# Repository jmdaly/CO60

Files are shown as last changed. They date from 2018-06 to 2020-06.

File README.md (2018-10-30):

# CO60 PCB

The CO60 was developed out of the desire to produce a 60% PCB that
appeals to many people and is readily available. CO60 is a portmanteau
of Community and 60% keyboard.

## Overview

The CO60 aims to meet the following design goals:

* Switches oriented such that the LEDs are South-facing, for
  compatibility with Cherry profile keycaps.

* USB Type-C support in both A to C and C to C configurations.

* QMK support.

* A variety of split spacebar configurations, including split 6.25U
  space and split 7U space.

* ESD protection circuitry, including data line protection and a
  polyfuse on the VCC line.

* Support for per-switch LED backlighting.

* Fits in standard 60% keyboard cases.

## Supported Layouts

The CO60 supports the [the following layouts](http://www.keyboard-layout-editor.com/#/gists/b488496b3a71c8192113c07e298be340).

## Motivation

There are a number of 60% keyboard PCBs available today, so it is important to
be clear about the reasons for developing a new one. This PCB is the only 60%
keyboard PCB that, to the best of my knowledge, satisfies ALL of the following
criteria:

* Support for MX switches oriented such that the LEDs are South
  facing, for compatibility with Cherry profile keycaps.

* Support for split spacebars, in both 6.25U and 7U configurations.

* USB Type-C connection that supports both A to C and C to C
  configurations.

* Open source hardware. This allows anybody to do a production run of the board
  at any point, and doesn't lock the design in with a particular vendor.

* QMK support.

* Based on an STM32F303 ARM MCU.

## Obtaining the Files

This repository contains several submodules, which in turn contain
KiCad libraries used in the PCB design. In order to clone the CO60
repository, and all of the library submodules, the following command
must be issued,

```
git clone --recursive https://github.com/jmdaly/CO60.git
```

## Acknowledgements

This PCB design would not have been possible without the help and previous work
of a number of people. In particular, great inspiration has been derived from
the [GH60 project](https://github.com/komar007/gh60), and [ai03's excellent
open source keyboard designs](https://github.com/ai03-2725). This includes the
use of ai03's KiCad [switch footprint
libraries](https://github.com/ai03-2725/MX_Alps_Hybrid.pretty) and his [USB
Type-C](https://github.com/ai03-2725/Type-C.pretty) KiCad footprint libraries.

The Banana Split V2 PCB provided inspiration for some of the bottom row
layouts. The Banana Split was the first 60% PCB to popularize the split
spacebar layout, and the folks at [The Van
Keyboards](https://thevankeyboards.com/) deserve a lot of credit for this
development.

The board outline libraries were created by amtra5, and full credit
goes to him for their design.

There is an active keyboard design community on the MechKeys discord. The
users there have been very helpful, and I've learned a significant
amount about PCB design from them.

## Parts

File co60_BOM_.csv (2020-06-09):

Component | References | Quantity Per PCB | Value | Footprint | Description | Part | Datasheet | LCSC PN | Product | Digi-Key_PN | Config | Manufacturer | Status | MPN | DK_Datasheet_Link | DK_Detail_Page | Category | Family | DigiKey Page
1 | C3 C4 C8 C9 C12 C13 C14 C15 C16 C17 C18 C19 C20 C21 C22 C23 C24 C25 C26 C27 | 20 | 100n | C_0603_1608Metric |  | C | https://product.tdk.com/info/en/catalog/datasheets/mlcc_commercial_hightemp_en.pdf | C1590 | C1608X8R1E104K080AA | 445-2500-1-ND
2 | C7 | 1 | 10n | C_0603_1608Metric |  | C | https://datasheet.lcsc.com/szlcsc/Samsung-Electro-Mechanics-CL10B103KB8NNNC_C1589.pdf | C1589 | CL10B103KB8NNNC
3 | C6 C10 C11 | 3 | 1u | C_0603_1608Metric |  | C | https://product.tdk.com/info/en/catalog/datasheets/mlcc_commercial_lowprofile_en.pdf | C59782 | CGB3B3JB1C105K055AB | 445-13234-1-ND
4 | C1 C2 | 2 | 30p | C_0603_1608Metric |  | C | https://datasheet.lcsc.com/szlcsc/Samsung-Electro-Mechanics-CL10C300JB8NNNC_C22397.pdf | C22397 | CL10C300JB8NNNC
5 | C5 | 1 | 4.7u | C_0603_1608Metric |  | C | http://www.samsungsem.com/kr/support/product-search/mlcc/__icsFiles/afieldfile/2016/12/21/CL10A475KA8NQNC_161221.pdf | C19666 | CL10A475KA8NQNC | 1276-1900-1-ND
6 | D1 D2 D3 D4 D5 D6 D7 D8 D9 D10 D11 D12 D13 D14 D15 D16 D17 D18 D19 D20 D21 D22 D23 D24 D25 D26 D27 D28 D29 D30 D31 D32 D33 D34 D35 D36 D37 D38 D39 D40 D41 D42 D43 D44 D45 D46 D47 D48 D49 D50 D51 D52 D53 D54 D55 D56 D57 D58 D59 D60 D61 D62 D63 D64 D65 D66 D67 D68 | 68 | D_Small | D_SOD-123 |  | D_Small | http://www.mccsemi.com/up_pdf/1N4148W(SOD123).pdf | C83528 | 1N4148W-TP | 1N4148WTPMSCT-ND
7 | F1 | 1 | 500mA | R_0805 |  | Polyfuse_Small | http://www.littelfuse.com/~/media/electronics/datasheets/resettable_ptcs/littelfuse_ptc_0805l_datasheet.pdf.pdf | C66452 | 0805L050WR | F2772CT-ND
8 | Q1 | 1 | FMMT493TA | SOT-23-3 | TRANS NPN 100V 1A SOT23-3 | FMMT493TA | https://www.diodes.com/assets/Datasheets/FMMT493.pdf | C47296 | FMMT493TA | FMMT493CT-ND |  | Diodes Incorporated | Active | FMMT493TA | https://www.diodes.com/assets/Datasheets/FMMT493.pdf | /product-detail/en/diodes-incorporated/FMMT493TA/FMMT493CT-ND/92663 | Discrete Semiconductor Products | Transistors - Bipolar (BJT) - Single
9 | R1 R2 R3 R4 R5 R6 R7 R8 R9 R10 R11 R12 R13 R14 R15 R16 R17 R18 R19 R20 R21 R22 R23 R24 R25 R26 R27 R28 R29 R30 R31 R32 R33 R34 R35 R36 R37 R38 R39 R40 R41 R42 R43 R44 R45 R46 R47 R48 R49 R50 R51 R52 R53 R54 R55 R56 R57 R58 R59 R60 R61 R62 R63 R64 R65 R66 R67 R68 | 68 | 560 | R_0603 |  | R_Small | https://www.mouser.ca/datasheet/2/427/mcx0x0xpro-223600.pdf | C137619 | MCT06030C5600FP500 | MCT0603-560-CFCT-ND
10 | RC8 | 1 | 10k | R_0603 |  | R | https://industrial.panasonic.com/ww/products/resistors/chip-resistors/general-purpose-chip-resistors/thick-film-chip-resistors/ERJ3GEYJ103V | C98220 | ERJ-3GEYJ103V | P10KGCT-ND
11 | RC1 RC9 | 2 | 470 | R_0603_1608Metric |  | R_Small | https://datasheet.lcsc.com/szlcsc/YAGEO-RC0603JR-07470RL_C114433.pdf | C114433 | RC0603JR-07470RL
12 | RC6 RC7 | 2 | 5.1k | R_0603 |  | R | https://www.seielect.com/Catalog/SEI-RMCF_RMCP.pdf | C14677 | RMCF0603JT5K10 | RMCF0603JT5K10CT-ND
13 | RGB1 RGB2 RGB3 RGB4 RGB5 RGB6 RGB7 RGB8 RGB9 RGB10 RGB11 RGB12 RGB13 RGB14 RGB15 RGB16 | 16 | WS2812B | LED_WS2812B_PLCC4_5.0x5.0mm_P3.2mm | RGB LED with integrated controller | WS2812B | https://cdn-shop.adafruit.com/datasheets/WS2812B.pdf | C114585
14 | SW1 | 1 | SW_Push | SW_SPST_TL3342 |  | SW_Push | https://www.e-switch.com/system/asset/product_line/data_sheet/165/TL3342.pdf | C92584 | TL3342F160QG/TR | EG2531CT-ND |  |  |  |  |  |  |  |  | https://www.digikey.ca/product-detail/en/e-switch/TL3342F160QG-TR/EG2531CT-ND/379004
15 | U4 | 1 | 74LVC1G34 | SOT-353_SC-70-5 |  | 74LVC1G34 |  | C94111
16 | U3 | 1 | NUF2221W1T2G | SOT-363 |  | NUF2221W1T2G | http://www.onsemi.com/pub/Collateral/NUF2221W1T2-D.PDF | C274624
17 | U1 | 1 | STM32F303CBTx | LQFP-48_7x7mm_Pitch0.5mm | ARM Cortex-M4 MCU, 128KB flash, 32KB RAM, 72MHz, 2-3.6V, 37 GPIO, LQFP-48 | STM32F303CBTx | http://www.st.com/st-web-ui/static/active/en/resource/technical/document/datasheet/DM00058181.pdf | C108516
18 | U2 | 1 | TLV70233_SOT23-5 | SOT-23-5 |  | TLV70233_SOT23-5-Regulator_Linear | http://www.ti.com/lit/ds/symlink/tlv702.pdf | C26833
19 | USB1 | 1 | HRO-TYPE-C-31-M-12 | HRO-TYPE-C-31-M-12-Assembly |  | HRO-TYPE-C-31-M-12 | https://datasheet.lcsc.com/szlcsc/Korean-Hroparts-Elec-TYPE-C-31-M-12_C165948.pdf | C165948
20 | Y1 | 1 | 8MHz | Crystal_SMD_5032-4pin_5.0x3.2mm |  | Crystal_GND24 | https://lcsc.com/product-detail/SMD-Crystals_SMD-5032-4P-8M-20pf-20ppm_C133333.html | C133333 | Zhejiang Abel Elec SMD-5032_4P8M20pf20ppm
Component Groups: | 38
Component Count: | 285
Fitted Components: | 193
Number of PCBs: | 1
Total components: | 193
Schematic Version:
Schematic Date:
PCB Variant: | ['default']
BoM Date: | Thu 04 Jun 2020 09:55:54 PM EDT
Schematic Source: | co60.sch
KiCad Version: | Eeschema 5.1.5-52549c5~84~ubuntu16.04.1

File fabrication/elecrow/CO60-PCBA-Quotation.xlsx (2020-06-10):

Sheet: PCB Specification
Your PCB Specification
PCB Quantity | 5pcs
Layer | 2layer
PCB Thickness | 1.6mm
Dimensions | 286mm*96mm
Castellated Hole | No
PCB Color | Purple
Surface Finish | ENIG
Copper Weight | 1oz
Text Color | White
Different Design | 1
Please find more PCB information on our on-line PCB ordering Page
https://www.elecrow.com/pcb-manufacturing.html

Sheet: BOM
CO60 Keyboard PCB
# | Reference | QTY | Value | Package | Manufacturer Part number | Description | SMD | THT | Original | Elecrow PN | LCSC PN | Note | Datasheet
1 | C3 C4 C8 C9 C12 C13 C14 C15 C16 C17 C18 C19 C20 C21 C22 C23 C24 C25 C26 C27 | 20 | 100n | 0603 | CL10B104KA8NNNC | Unpolarized capacitor | 40 |  | N |  | C1590 | 10% tolerance or less | https://datasheet.lcsc.com/szlcsc/1811092010_Samsung-Electro-Mechanics-CL10B104KA8NNNC_C1590.pdf
2 | C7 | 1 | 10n | 0603 | CL10B103KB8NNNC | Unpolarized capacitor | 2 |  | N |  | C1589 | 10% tolerance or less | https://datasheet.lcsc.com/szlcsc/Samsung-Electro-Mechanics-CL10B103KB8NNNC_C1589.pdf
3 | C6 C10 C11 | 3 | 1u | 0603 | CL10B105KO8NNNC | Unpolarized capacitor | 6 |  | N |  | C59782 | 10% tolerance or less | https://datasheet.lcsc.com/szlcsc/1810261512_Samsung-Electro-Mechanics-CL10B105KO8NNNC_C59782.pdf
4 | C1 C2 | 2 | 30p | 0603 | CL10C300JB8NNNC | Unpolarized capacitor | 4 |  | N |  | C22397 | 10% tolerance or less | https://datasheet.lcsc.com/szlcsc/Samsung-Electro-Mechanics-CL10C300JB8NNNC_C22397.pdf
5 | C5 | 1 | 4.7u | 0603 | CL10A475KO8NNNC | Unpolarized capacitor | 2 |  | N |  | C19666 | 10% tolerance or less | https://datasheet.lcsc.com/szlcsc/1810261514_Samsung-Electro-Mechanics-CL10A475KO8NNNC_C19666.pdf
6 | D1 D2 D3 D4 D5 D6 D7 D8 D9 D10 D11 D12 D13 D14 D15 D16 D17 D18 D19 D20 D21 D22 D23 D24 D25 D26 D27 D28 D29 D30 D31 D32 D33 D34 D35 D36 D37 D38 D39 D40 D41 D42 D43 D44 D45 D46 D47 D48 D49 D50 D51 D52 D53 D54 D55 D56 D57 D58 D59 D60 D61 D62 D63 D64 D65 D66 D67 D68 | 68 | D | SOD-123 | 1N4148W-7-F | Diode | 136 |  | N |  | C83528 |  | https://datasheet.lcsc.com/szlcsc/1809282109_Diodes-Incorporated-1N4148W-7-F_C83528.pdf
7 | F1 | 1 | 500mA | 0805 | SMD0805-050 | Polyfuse | 2 |  | N |  | C66452 |  | https://datasheet.lcsc.com/szlcsc/1808132010_TECHFUSE-SMD0805-050_C66452.pdf
8 | Q1 | 1 | FMMT495TA | SOT-23-3 | FMMT495TA | BJT | 3 |  | N |  | C47296 |  | https://datasheet.lcsc.com/szlcsc/1809191942_Diodes-Incorporated-FMMT495TA_C47296.pdf
9 | R1 R2 R3 R4 R5 R6 R7 R8 R9 R10 R11 R12 R13 R14 R15 R16 R17 R18 R19 R20 R21 R22 R23 R24 R25 R26 R27 R28 R29 R30 R31 R32 R33 R34 R35 R36 R37 R38 R39 R40 R41 R42 R43 R44 R45 R46 R47 R48 R49 R50 R51 R52 R53 R54 R55 R56 R57 R58 R59 R60 R61 R62 R63 R64 R65 R66 R67 R68 | 68 | 560 | 0603 | RC0603JR-07560RL | Resistor | 136 |  | N |  | C137619 | 5% tolerance or less | https://datasheet.lcsc.com/szlcsc/1811082133_YAGEO-RC0603JR-07560RL_C137619.pdf
10 | RC8 | 1 | 10k | 0603 | RC0603FR-0710KL | Resistor | 2 |  | N |  | C98220 | 5% tolerance or less | https://datasheet.lcsc.com/szlcsc/1811101934_YAGEO-RC0603FR-0710KL_C98220.pdf
11 | RC1 RC9 | 2 | 470 | 0603 | RC0603JR-07470RL | Resistor | 4 |  | N |  | C114433 | 5% tolerance or less | https://datasheet.lcsc.com/szlcsc/YAGEO-RC0603JR-07470RL_C114433.pdf
12 | RC6 RC7 | 2 | 5.1k | 0603 | RC0603JR-075K1L | Resistor | 4 |  | N |  | C14677 | 5% tolerance or less | https://datasheet.lcsc.com/szlcsc/1810241812_YAGEO-RC0603JR-075K1L_C14677.pdf
13 | RGB1 RGB2 RGB3 RGB4 RGB5 RGB6 RGB7 RGB8 RGB9 RGB10 RGB11 RGB12 RGB13 RGB14 RGB15 RGB16 | 16 | WS2812B | LED_WS2812B_PLCC4_5.0x5.0mm_P3.2mm | WS2812B | RGB LED | 64 |  | N |  | C114585 |  | https://cdn-shop.adafruit.com/datasheets/WS2812B.pdf
14 | SW1 | 1 | SW_Push | SW_SPST_TL3342 | K2-1187SQ-A4SW-06 | Switch | 4 |  | N |  | C92584 |  | https://datasheet.lcsc.com/szlcsc/1811082127_Korean-Hroparts-Elec-K2-1187SQ-A4SW-06_C92584.pdf
15 | U4 | 1 | 74LVC1G34 | SOT-353 | 74LVC1G34SE-7 | Level shifter | 5 |  | N |  | C94111 |  | https://datasheet.lcsc.com/szlcsc/1811061209_Diodes-Incorporated-74LVC1G34SE-7_C94111.pdf
16 | U3 | 1 | NUF2221W1T2G | SOT-363 | NUF2221W1T2G | USB Termination | 6 |  | N |  | C274624 |  | http://www.onsemi.com/pub/Collateral/NUF2221W1T2-D.PDF
17 | U1 | 1 | STM32F303CBTx | LQFP-48_7x7mm_Pitch0.5mm | STM32F303CBTx | ARM Cortex-M4 MCU, 128KB flash, 32KB RAM, 72MHz, 2-3.6V, 37 GPIO, LQFP-48 | 48 |  | N |  | C108516 |  | http://www.st.com/st-web-ui/static/active/en/resource/technical/document/datasheet/DM00058181.pdf
18 | U2 | 1 | TLV70233_SOT23-5 | SOT-23-5 | TLV70233_SOT23-5 | Linear Regulator | 5 |  | N |  | C26833 |  | http://www.ti.com/lit/ds/symlink/tlv702.pdf
19 | USB1 | 1 | HRO-TYPE-C-31-M-12 | HRO-TYPE-C-31-M-12-Assembly | HRO-TYPE-C-31-M-12 | USB Connector | 12 |  | N |  | C165948 |  | https://datasheet.lcsc.com/szlcsc/Korean-Hroparts-Elec-TYPE-C-31-M-12_C165948.pdf
20 | Y1 | 1 | 8MHz | Crystal_SMD_5032-4pin_5.0x3.2mm | SMD-5032_4P8M20pf20ppm | Crystal | 4 |  | N |  | C133333 |  | https://lcsc.com/product-detail/SMD-Crystals_SMD-5032-4P-8M-20pf-20ppm_C133333.html
 |  |  |  |  |  | total： | 489 | 0
 | Declare：
 | 1、If the component should be original like Digi-key or Mouser，the component must have complete Manufacture part number

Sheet: Position File
Designator | Footprint | Center-X(mm) | Center-Y(mm) | Layer | Rotation
C1 | C_0603_1608Metric | 44.2314 | 62.35 | BottomLayer | 0
C2 | C_0603_1608Metric | 44.1814 | 55.82 | BottomLayer | 180
C3 | C_0603_1608Metric | 33.2114 | 60.41 | BottomLayer | 180
C4 | C_0603_1608Metric | 22.2614 | 55.75 | BottomLayer | 270
C5 | C_0603_1608Metric | 20.2294 | 55.75 | BottomLayer | 270
C6 | C_0603_1608Metric | 41.51376 | 53.29428 | BottomLayer | 90
C7 | C_0603_1608Metric | 39.3314 | 53.286 | BottomLayer | 90
C8 | C_0603_1608Metric | 26.8414 | 46.9894 | BottomLayer | 0
C9 | C_0603_1608Metric | 41.9314 | 50.62 | BottomLayer | 0
C10 | C_0603_1608Metric | 18.3314 | 63.92 | BottomLayer | 0
C11 | C_0603_1608Metric | 15.748 | 58.3946 | BottomLayer | 270
C12 | C_0603_1608Metric | 42.2214 | 76.18 | BottomLayer | 270
C13 | C_0603_1608Metric | 72.6514 | 75.59 | BottomLayer | 270
C14 | C_0603_1608Metric | 99.5014 | 75.66 | BottomLayer | 270
C15 | C_0603_1608Metric | 135.0314 | 76.47 | BottomLayer | 270
C16 | C_0603_1608Metric | 168.1614 | 75.68 | BottomLayer | 270
C17 | C_0603_1608Metric | 202.6714 | 76.03 | BottomLayer | 270
C18 | C_0603_1608Metric | 236.0514 | 75.92 | BottomLayer | 270
C19 | C_0603_1608Metric | 269.4814 | 75.76 | BottomLayer | 270
C20 | C_0603_1608Metric | 266.7414 | 18.89 | BottomLayer | 270
C21 | C_0603_1608Metric | 236.0714 | 20.07 | BottomLayer | 270
C22 | C_0603_1608Metric | 193.2214 | 22.81 | BottomLayer | 90
C23 | C_0603_1608Metric | 168.9714 | 20.76 | BottomLayer | 0
C24 | C_0603_1608Metric | 133.9114 | 18.44 | BottomLayer | 270
C25 | C_0603_1608Metric | 100.0314 | 23.07 | BottomLayer | 180
C26 | C_0603_1608Metric | 72.0214 | 18.48 | BottomLayer | 270
C27 | C_0603_1608Metric | 23.0814 | 18.95 | BottomLayer | 270
D1 | D_SOD-123 | 5.8674 | 91.44 | BottomLayer | 180
D2 | D_SOD-123 | 36.522025 | 86.598125 | BottomLayer | 90
D3 | D_SOD-123 | 55.572025 | 86.598125 | BottomLayer | 90
D4 | D_SOD-123 | 74.7814 | 88.93 | BottomLayer | 180
D5 | D_SOD-123 | 93.672025 | 86.598125 | BottomLayer | 90
D6 | D_SOD-123 | 112.722025 | 86.598125 | BottomLayer | 90
D7 | D_SOD-123 | 131.772025 | 86.598125 | BottomLayer | 90
D8 | D_SOD-123 | 150.822025 | 86.598125 | BottomLayer | 90
D9 | D_SOD-123 | 169.872025 | 86.598125 | BottomLayer | 90
D10 | D_SOD-123 | 188.7714 | 88.85 | BottomLayer | 180
D11 | D_SOD-123 | 207.972025 | 86.598125 | BottomLayer | 90
D12 | D_SOD-123 | 227.022025 | 86.598125 | BottomLayer | 90
D13 | D_SOD-123 | 246.072025 | 86.598125 | BottomLayer | 90
D14 | D_SOD-123 | 265.7094 | 90.17 | BottomLayer | 90
D15 | D_SOD-123 | 281.790775 | 90.17 | BottomLayer | 90
D16 | D_SOD-123 | 5.565775 | 71.12 | BottomLayer | 90
D17 | D_SOD-123 | 45.9314 | 69.42 | BottomLayer | 90
D18 | D_SOD-123 | 65.097025 | 67.548125 | BottomLayer | 90
D19 | D_SOD-123 | 84.147025 | 67.548125 | BottomLayer | 90
D20 | D_SOD-123 | 103.197025 | 67.548125 | BottomLayer | 90
D21 | D_SOD-123 | 122.247025 | 67.548125 | BottomLayer | 90
D22 | D_SOD-123 | 141.297025 | 67.548125 | BottomLayer | 90
D23 | D_SOD-123 | 160.347025 | 67.548125 | BottomLayer | 90
D24 | D_SOD-123 | 179.397025 | 67.548125 | BottomLayer | 90
D25 | D_SOD-123 | 198.447025 | 67.548125 | BottomLayer | 90
D26 | D_SOD-123 | 217.497025 | 67.548125 | BottomLayer | 90
D27 | D_SOD-123 | 236.547025 | 67.548125 | BottomLayer | 90
D28 | D_SOD-123 | 254.4064 | 69.929375 | BottomLayer | 90
D29 | D_SOD-123 | 277.028275 | 71.12 | BottomLayer | 90
D30 | D_SOD-123 | 21.0439 | 42.545 | BottomLayer | 90
D31 | D_SOD-123 | 50.809525 | 48.498125 | BottomLayer | 90
D32 | D_SOD-123 | 69.859525 | 48.498125 | BottomLayer | 90
D33 | D_SOD-123 | 88.909525 | 48.498125 | BottomLayer | 90
D34 | D_SOD-123 | 107.959525 | 48.498125 | BottomLayer | 90
D35 | D_SOD-123 | 110.8329 | 48.5003 | BottomLayer | 90
D36 | D_SOD-123 | 146.059525 | 48.498125 | BottomLayer | 90
D37 | D_SOD-123 | 165.109525 | 48.498125 | BottomLayer | 90
D38 | D_SOD-123 | 184.159525 | 48.498125 | BottomLayer | 90
D39 | D_SOD-123 | 203.209525 | 48.498125 | BottomLayer | 90
D40 | D_SOD-123 | 222.259525 | 48.498125 | BottomLayer | 90
D41 | D_SOD-123 | 241.309525 | 48.498125 | BottomLayer | 90
D42 | D_SOD-123 | 259.1689 | 54.45125 | BottomLayer | 90
D43 | D_SOD-123 | 272.265775 | 47.3075 | BottomLayer | 90
D44 | D_SOD-123 | 3.184525 | 29.448125 | BottomLayer | 90
D45 | D_SOD-123 | 41.284525 | 29.448125 | BottomLayer | 90
D46 | D_SOD-123 | 60.334525 | 29.448125 | BottomLayer | 90
D47 | D_SOD-123 | 79.384525 | 29.448125 | BottomLayer | 90
D48 | D_SOD-123 | 98.434525 | 29.448125 | BottomLayer | 90
D49 | D_SOD-123 | 117.484525 | 29.448125 | BottomLayer | 90
D50 | D_SOD-123 | 136.534525 | 29.448125 | BottomLayer | 90
D51 | D_SOD-123 | 155.584525 | 29.448125 | BottomLayer | 90
D52 | D_SOD-123 | 174.634525 | 29.448125 | BottomLayer | 90
D53 | D_SOD-123 | 193.684525 | 29.448125 | BottomLayer | 90
D54 | D_SOD-123 | 212.734525 | 29.448125 | BottomLayer | 90
D55 | D_SOD-123 | 231.784525 | 29.448125 | BottomLayer | 90
D56 | D_SOD-123 | 267.503275 | 29.448125 | BottomLayer | 90
D57 | D_SOD-123 | 281.790775 | 23.495 | BottomLayer | 90
D58 | D_SOD-123 | 22.733 | 13.8176 | BottomLayer | 90
D59 | D_SOD-123 | 46.047025 | 10.398125 | BottomLayer | 90
D60 | D_SOD-123 | 69.859525 | 10.398125 | BottomLayer | 90
D61 | D_SOD-123 | 110.340775 | 10.398125 | BottomLayer | 90
D62 | D_SOD-123 | 150.822025 | 9.2075 | BottomLayer | 90
D63 | D_SOD-123 | 155.584525 | 9.2075 | BottomLayer | 90
D64 | D_SOD-123 | 207.972025 | 15.160625 | BottomLayer | 90
D65 | D_SOD-123 | 211.5439 | 15.160625 | BottomLayer | 90
D66 | D_SOD-123 | 243.690775 | 16.35125 | BottomLayer | 90
D67 | D_SOD-123 | 263.7814 | 13.07 | BottomLayer | 90
D68 | D_SOD-123 | 281.790775 | 13.97 | BottomLayer | 90
F1 | R_0805 | 14.2314 | 82.27 | BottomLayer | 90
Q1 | SOT-23-3 | 21.1074 | 37.084 | BottomLayer | 270
R1 | R_0603 | 4.37515 | 79.454375 | BottomLayer | 90
R2 | R_0603 | 23.42515 | 79.454375 | BottomLayer | 90
R3 | R_0603 | 42.47515 | 79.454375 | BottomLayer | 90
R4 | R_0603 | 61.2714 | 80.52 | BottomLayer | 90
R5 | R_0603 | 80.57515 | 79.454375 | BottomLayer | 90
R6 | R_0603 | 99.62515 | 79.454375 | BottomLayer | 90
R7 | R_0603 | 118.67515 | 79.454375 | BottomLayer | 90
R8 | R_0603 | 137.72515 | 79.454375 | BottomLayer | 90
R9 | R_0603 | 156.77515 | 79.454375 | BottomLayer | 90
R10 | R_0603 | 175.82515 | 79.454375 | BottomLayer | 90
R11 | R_0603 | 194.1614 | 80.51 | BottomLayer | 90
R12 | R_0603 | 213.92515 | 79.454375 | BottomLayer | 90
R13 | R_0603 | 232.8514 | 80.59 | BottomLayer | 90
R14 | R_0603 | 250.834525 | 79.454375 | BottomLayer | 90
R15 | R_0603 | 271.07515 | 79.454375 | BottomLayer | 90
R16 | R_0603 | 9.13765 | 60.404375 | BottomLayer | 90
R17 | R_0603 | 33.0314 | 63.52 | BottomLayer | 90
R18 | R_0603 | 62.1514 | 60.42 | BottomLayer | 90
R19 | R_0603 | 71.05015 | 60.404375 | BottomLayer | 90
R20 | R_0603 | 90.10015 | 60.404375 | BottomLayer | 90
R21 | R_0603 | 109.15015 | 60.404375 | BottomLayer | 90
R22 | R_0603 | 128.20015 | 60.404375 | BottomLayer | 90
R23 | R_0603 | 147.25015 | 60.404375 | BottomLayer | 90
R24 | R_0603 | 166.30015 | 60.404375 | BottomLayer | 90
R25 | R_0603 | 185.35015 | 60.404375 | BottomLayer | 90
R26 | R_0603 | 204.40015 | 60.404375 | BottomLayer | 90
R27 | R_0603 | 223.45015 | 60.404375 | BottomLayer | 90
R28 | R_0603 | 242.50015 | 60.404375 | BottomLayer | 90
R29 | R_0603 | 266.31265 | 60.404375 | BottomLayer | 90
R30 | R_0603 | 7.947025 | 43.735625 | BottomLayer | 90
R31 | R_0603 | 37.71265 | 41.354375 | BottomLayer | 90
R32 | R_0603 | 56.76265 | 41.354375 | BottomLayer | 90
R33 | R_0603 | 75.81265 | 41.354375 | BottomLayer | 90
R34 | R_0603 | 94.86265 | 41.354375 | BottomLayer | 90
R35 | R_0603 | 113.91265 | 41.354375 | BottomLayer | 90
R36 | R_0603 | 132.96265 | 41.354375 | BottomLayer | 90
R37 | R_0603 | 152.01265 | 41.354375 | BottomLayer | 90
R38 | R_0603 | 171.06265 | 41.354375 | BottomLayer | 90
R39 | R_0603 | 190.11265 | 41.354375 | BottomLayer | 90
R40 | R_0603 | 209.16265 | 41.354375 | BottomLayer | 90
R41 | R_0603 | 228.21265 | 41.354375 | BottomLayer | 90
R42 | R_0603 | 247.26265 | 41.354375 | BottomLayer | 90
R43 | R_0603 | 259.1689 | 41.354375 | BottomLayer | 90
R44 | R_0603 | 6.7564 | 24.685625 | BottomLayer | 90
R45 | R_0603 | 28.18765 | 22.304375 | BottomLayer | 90
R46 | R_0603 | 47.23765 | 22.304375 | BottomLayer | 90
R47 | R_0603 | 66.1214 | 23.42 | BottomLayer | 90
R48 | R_0603 | 85.33765 | 22.304375 | BottomLayer | 90
R49 | R_0603 | 104.38765 | 22.304375 | BottomLayer | 90
R50 | R_0603 | 123.2814 | 23.32 | BottomLayer | 90
R51 | R_0603 | 142.48765 | 22.304375 | BottomLayer | 90
R52 | R_0603 | 161.4414 | 23.29 | BottomLayer | 90
R53 | R_0603 | 180.58765 | 22.304375 | BottomLayer | 90
R54 | R_0603 | 199.63765 | 22.304375 | BottomLayer | 90
R55 | R_0603 | 218.68765 | 22.304375 | BottomLayer | 90
R56 | R_0603 | 254.4064 | 22.304375 | BottomLayer | 90
R57 | R_0603 | 275.83765 | 19.923125 | BottomLayer | 0
R58 | R_0603 | 6.7564 | 3.254375 | BottomLayer | 90
R59 | R_0603 | 30.5689 | 3.254375 | BottomLayer | 90
R60 | R_0603 | 54.3814 | 3.254375 | BottomLayer | 90
R61 | R_0603 | 117.6782 | 3.2258 | BottomLayer | 90
R62 | R_0603 | 121.0564 | 3.254375 | BottomLayer | 90
R63 | R_0603 | 159.1564 | 4.445 | BottomLayer | 90
R64 | R_0603 | 206.7814 | 3.254375 | BottomLayer | 90
R65 | R_0603 | 230.5939 | 3.254375 | BottomLayer | 90
R66 | R_0603 | 234.165775 | 3.254375 | BottomLayer | 90
R67 | R_0603 | 253.1364 | 2.413 | BottomLayer | 270
R68 | R_0603 | 267.7414 | 2.032 | BottomLayer | 90
RC1 | R_0603_1608Metric | 29.2354 | 43.18 | BottomLayer | 0
RC6 | R_0603 | 12.065 | 87.4268 | BottomLayer | 270
RC7 | R_0603 | 26.0314 | 91.07 | BottomLayer | 180
RC8 | R_0603 | 24.6314 | 43.72 | BottomLayer | 0
RC9 | R_0603_1608Metric | 30.5689 | 76.82 | BottomLayer | 180
RGB1 | LED_WS2812B_PLCC4_5.0x5.0mm_P3.2mm | 36.6014 | 76.87 | BottomLayer | 180
RGB2 | LED_WS2812B_PLCC4_5.0x5.0mm_P3.2mm | 67.0514 | 75.05 | BottomLayer | 180
RGB3 | LED_WS2812B_PLCC4_5.0x5.0mm_P3.2mm | 93.9714 | 76.24 | BottomLayer | 180
RGB4 | LED_WS2812B_PLCC4_5.0x5.0mm_P3.2mm | 129.5014 | 75.82 | BottomLayer | 180
RGB5 | LED_WS2812B_PLCC4_5.0x5.0mm_P3.2mm | 162.9514 | 74.99 | BottomLayer | 180
RGB6 | LED_WS2812B_PLCC4_5.0x5.0mm_P3.2mm | 197.1514 | 75.68 | BottomLayer | 180
RGB7 | LED_WS2812B_PLCC4_5.0x5.0mm_P3.2mm | 230.2814 | 76.07 | BottomLayer | 180
RGB8 | LED_WS2812B_PLCC4_5.0x5.0mm_P3.2mm | 263.8714 | 75.18 | BottomLayer | 180
RGB9 | LED_WS2812B_PLCC4_5.0x5.0mm_P3.2mm | 261.8014 | 18.75 | BottomLayer | 180
RGB10 | LED_WS2812B_PLCC4_5.0x5.0mm_P3.2mm | 230.4914 | 19.62 | BottomLayer | 180
RGB11 | LED_WS2812B_PLCC4_5.0x5.0mm_P3.2mm | 187.7814 | 18.82 | BottomLayer | 180
RGB12 | LED_WS2812B_PLCC4_5.0x5.0mm_P3.2mm | 163.4214 | 18.8 | BottomLayer | 180
RGB13 | LED_WS2812B_PLCC4_5.0x5.0mm_P3.2mm | 128.3114 | 18.65 | BottomLayer | 180
RGB14 | LED_WS2812B_PLCC4_5.0x5.0mm_P3.2mm | 98.0314 | 19.07 | BottomLayer | 180
RGB15 | LED_WS2812B_PLCC4_5.0x5.0mm_P3.2mm | 66.5314 | 18.82 | BottomLayer | 180
RGB16 | LED_WS2812B_PLCC4_5.0x5.0mm_P3.2mm | 16.9614 | 18.8 | BottomLayer | 180
SW1 | SW_SPST_TL3342 | 28.0924 | 36.576 | BottomLayer | 270
U1 | LQFP-48_7x7mm_Pitch0.5mm | 30.5314 | 53.72 | BottomLayer | 180
U2 | SOT-23-5 | 18.9314 | 60.32 | BottomLayer | 270
U3 | SOT-363 | 18.1102 | 80.1878 | BottomLayer | 180
U4 | SOT-353_SC-70-5 | 24.4014 | 75.28 | BottomLayer | 0
USB1 | HRO-TYPE-C-31-M-12-Assembly | 18.2134 | 96.5708 | BottomLayer | 0
Y1 | Crystal_SMD_5032-4pin_5.0x3.2mm | 44.3814 | 59.15 | BottomLayer | 180

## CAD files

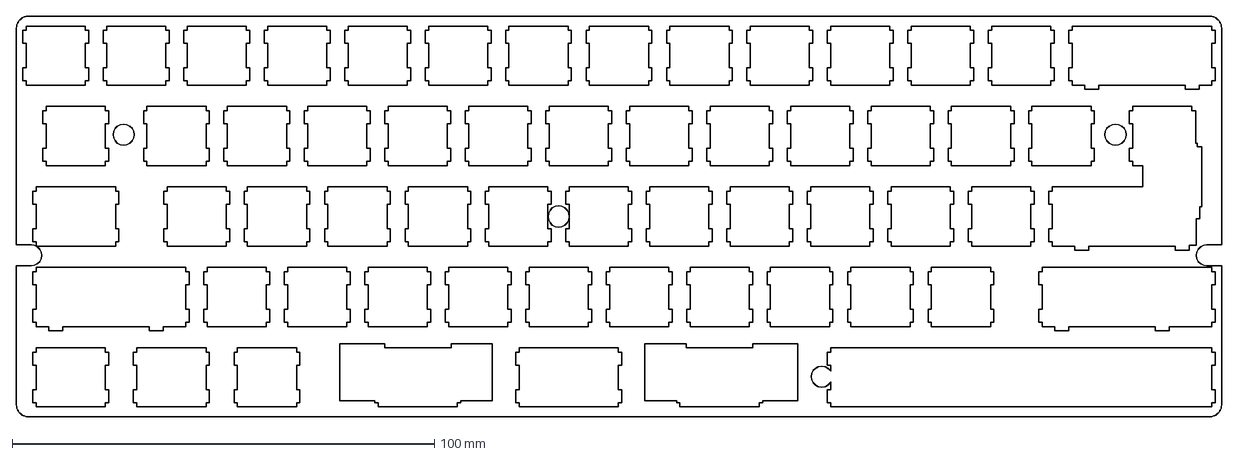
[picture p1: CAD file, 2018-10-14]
plates/co60_6.25u_plate.dxf
285.4 x 94.9 mm

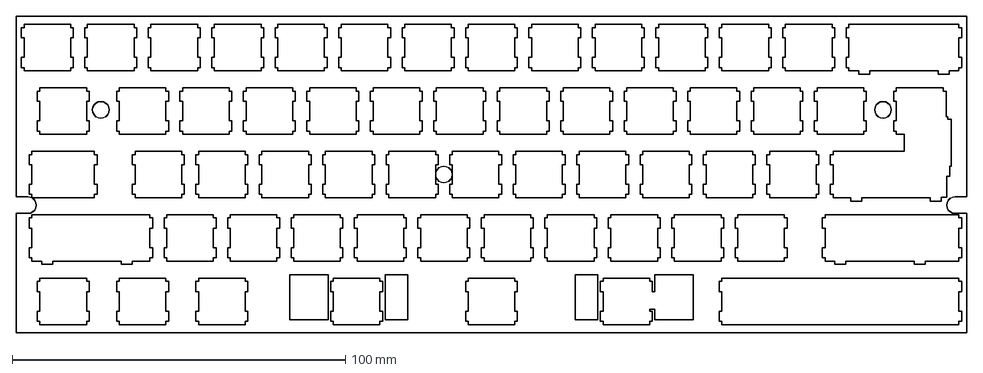
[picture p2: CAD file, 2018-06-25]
plates/co60_7u_plate.dxf
285.4 x 94.9 mm

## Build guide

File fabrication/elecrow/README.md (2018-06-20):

This directory contains the spreadsheet that was sent to Elecrow in
order to obtain a quotation and then to provide the information they
required for manufacturing and assembly of the CO60.

Provided that Elecrow has not changed their templates, a person
interested in having Elecrow do a production run of the board,
including assembly, should be able to submit the spreadsheet in this
directory, along with the Gerbers, and have the boards produced.

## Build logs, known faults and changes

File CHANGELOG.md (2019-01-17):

# Changelog
All notable changes to this project will be documented in this file.

## [Unreleased]

## [Rev. 7] - 2019-01-17

### Changed
- This revision adds 16 RGB LEDs to the bottom of the PCB
  to be used as underglow. Note that, in order to add the RGB
  LEDs, I had to re-route significant portions of the PCB. As
  a result, the matrix layout has changed. Rev. 7 firmware is
  incompatible with Rev. 6 firmware.

## [Rev. 6] - 2018-11-19

### Changed
- This revision of the PCB now uses an STM32F303 microcontroller
  instead of an Atmega 32u4. The layouts remain the same, but
  the firmware for Rev. 6 is incompatible with previous revisions.

## [Rev. 5] - 2018-08-28

### Changed
- USB connector from Amphenol Type C to Korean HRO Type-C.
  I believe this new connector will not conflict with switches
  when they are installed. The legs of the Amphenol connector
  conflicted with the switches.

## [Rev. 4] - 2018-07-22

### Added
- Initial versions of plate files to accompany PCB.

### Changed
- Fix pin assignments on transistor used for LED backlighting.
  Prior to this fix, backlighting did not work at all. This fix
  should resolve that issue.

## [Rev. 3] - 2018-06-20

### Added
- More PCB material under USB connector so that its through hole
  pins are entirely within the board.

- Spreadsheet sent to Elecrow for fabrication and assembly. This
  is the revision of the CO60 that was sent to Elecrow for initial
  fabrication and assembly.

### Changed
- Increase width of one VCC trace that was too thin.

- Move some silk screen component labels around so they are
  more visible.

- Clean up routing for some traces to give more clearance around
  other objects.

- Improve ground plane coverage and ensure the two ground
  planes only connect at a single location.

- Move board origin to lower left corner of board.

- Move D4 and D10 to ensure compatibility with some cases.

- Move R18 in order to clean up some traces nearby.

## [Rev. 2] - 2018-06-04

### Added
- This CHANGELOG file to track changes between revisions.

### Changed
- Move the USB connector farther toward the top of the board. This is
  to prevent any issues with the USB housing overlapping with holes in
  the board.

- Clean up some traces near drill holes.

## Rev. 1 - 2018-05-29

### Added
- Tag to note the first completed revision. This is the version that
  was sent to JLCPCB for initial prototyping.

[Unreleased]: https://github.com/jmdaly/CO60/compare/Rev.7...HEAD
[Rev. 7]: https://github.com/jmdaly/CO60/compare/Rev.6...Rev.7
[Rev. 6]: https://github.com/jmdaly/CO60/compare/Rev.5...Rev.6
[Rev. 5]: https://github.com/jmdaly/CO60/compare/Rev.4...Rev.5
[Rev. 4]: https://github.com/jmdaly/CO60/compare/Rev.3...Rev.4
[Rev. 3]: https://github.com/jmdaly/CO60/compare/Rev.2...Rev.3
[Rev. 2]: https://github.com/jmdaly/CO60/compare/Rev.1...Rev.2

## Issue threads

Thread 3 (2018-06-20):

Logo Design

zuuritaly, 2018-06-20:
Hello!

I'm a graphic designer and I like to support open source projects. I would like to design for free a logo for your project if you interested, I will be happy to work with you!

Best Regards

Zuur

Graphic Designer

jmdaly, 2018-06-21:
Hi Zuur,

That's awesome! I'd love to work with you on that. Just let me know how you'd like to proceed, and we can go from there :)

Thanks so much,
John

zuuritaly, 2018-06-23:
Hello @jmdaly ,
I'm a graphic designer and I design logos for open source projects for free, you dont have to pay nothing.

Usually after the project owner accepts that I design the logo, I ask the following questions to assist me in the creative process:

Do you have something in your mind for the logo?
Do you want something specific for the logo?
What colors do you want in the logo?

With your answers I will design a logo for your project and if you like it you can keep it and used.

Best Regards

Zuur

jmdaly, 2018-06-25:
Great! So I don't have anything too specific in mind for a logo, but I'll tell you what I've been thinking about. This project is an open hardware project where I'm aiming to bring a printed circuit board (PCB) design to the mechanical keyboard community for their use. Basically, mechanical keyboard enthusiasts would use this PCB to build a mechanical keyboard.

The project name, CO60, is a combination of COmmunity and 60%, 60% being the form factor of the keyboard PCB I've designed. My goal is to make this a community project - something that people can add to, contribute to, do production runs of, etc. With that in mind, thinking of a logo that relates to the idea of community has been on my mind. Ideas I've considered are a city skyline, which would show a place where there are a lot of communities, or groups of people, which would symbolize community.

I don't have any specific colors in mind. If we settle on a logo, I would likely want to put it on the PCB for a production run. For that, the logo would need to look good in a monochrome color, since the silk screen on a PCB is only a single color. But the logo itself doesn't need to be monochrome.

Hope that answers your questions. Definitely feel free to ask any follow-up questions you may have :)

Thanks again,
John

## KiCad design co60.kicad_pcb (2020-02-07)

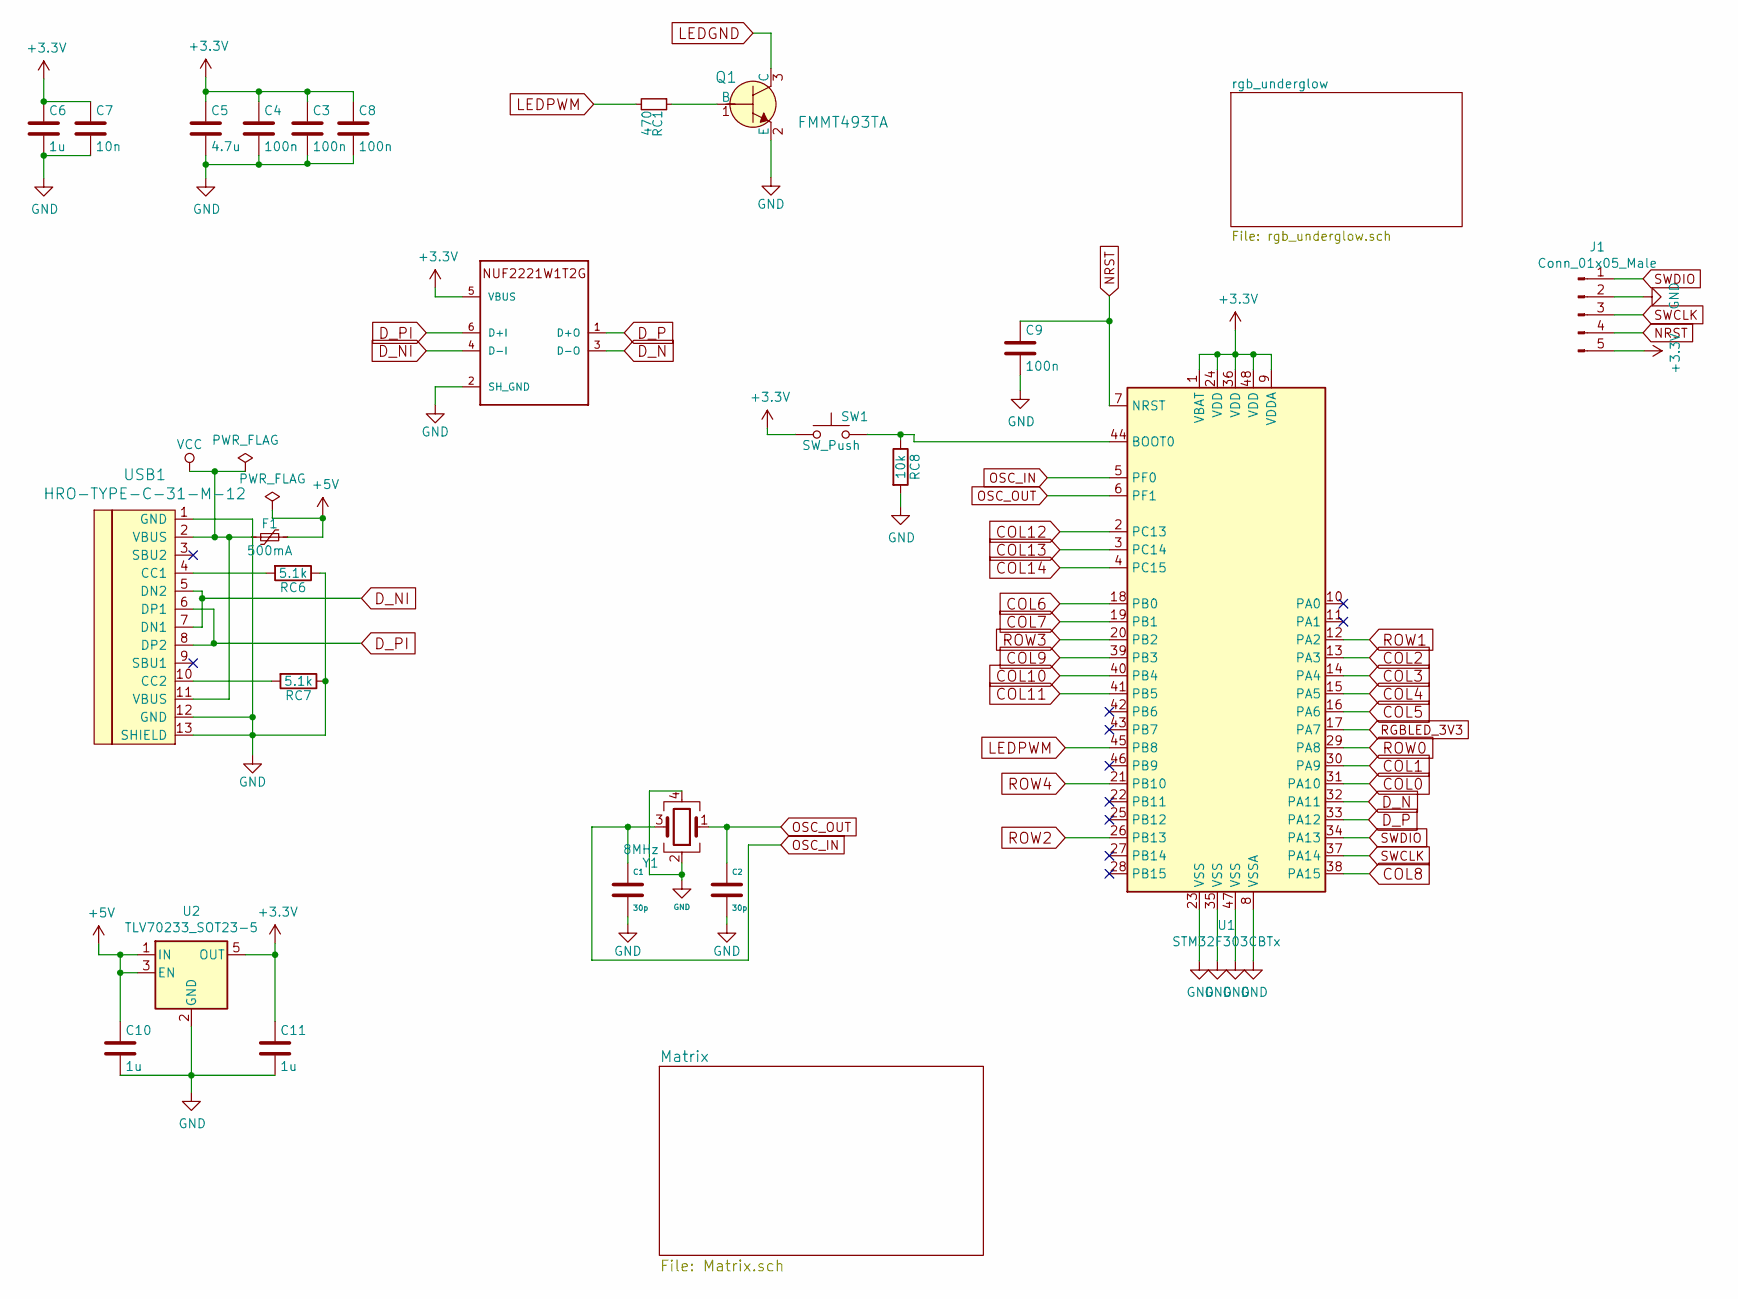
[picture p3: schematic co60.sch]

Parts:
C1, C2: 30p; C_0603_1608Metric; LCSC PN C22397
C3, C4, C8, C9: 100n; C_0603_1608Metric; Digi-Key_PN 445-2500-1-ND
C5: 4.7u; C_0603_1608Metric; Digi-Key_PN 1276-1900-1-ND
C6, C10, C11: 1u; C_0603_1608Metric; Digi-Key_PN 445-13234-1-ND
C7: 10n; C_0603_1608Metric; LCSC PN C1589
F1: 500mA; R_0805; Digi-Key_PN F2772CT-ND
J1: Conn_01x05_Male; PinHeader_1x05_P2.54mm_Vertical
Q1: FMMT493TA; SOT-23-3; MPN FMMT493TA; Digi-Key_PN FMMT493CT-ND
RC1: 470; R_0603_1608Metric; LCSC PN C114433
RC6: 5.1k; R_0603; Digi-Key_PN RMCF0603JT5K10CT-ND
RC7: 5.1k; R_0603; LCSC PN C14677
RC8: 10k; R_0603; Digi-Key_PN P10KGCT-ND
SW1: SW_Push; SW_SPST_TL3342; Digi-Key_PN EG2531CT-ND
U1: STM32F303CBTx; LQFP-48_7x7mm_Pitch0.5mm; LCSC PN C108516
U2: TLV70233_SOT23-5; SOT-23-5; LCSC PN C26833
U3: NUF2221W1T2G; SOT-363; LCSC PN C274624
USB1: HRO-TYPE-C-31-M-12; HRO-TYPE-C-31-M-12-Assembly; LCSC PN C165948
Y1: 8MHz; Crystal_SMD_5032-4pin_5.0x3.2mm; LCSC PN C133333

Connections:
+3V3: C3.1, C4.1, C5.1, C6.1, C7.1, C8.1, C11.1, J1.5, SW1.1, U1.1 (VBAT), U1.9 (VDDA), U1.24 (VDD), U1.36 (VDD), U1.48 (VDD), U2.5 (OUT), U3.5 (VBUS)
+5V: C10.1, F1.1, U2.1 (IN), U2.3 (EN); also elsewhere on the board
COL0: U1.31 (PA10); also elsewhere on the board
COL1: U1.30 (PA9); also elsewhere on the board
COL2: U1.13 (PA3); also elsewhere on the board
COL3: U1.14 (PA4); also elsewhere on the board
COL4: U1.15 (PA5); also elsewhere on the board
COL5: U1.16 (PA6); also elsewhere on the board
COL6: U1.18 (PB0); also elsewhere on the board
COL7: U1.19 (PB1); also elsewhere on the board
COL8: U1.38 (PA15); also elsewhere on the board
COL9: U1.39 (PB3); also elsewhere on the board
COL10: U1.40 (PB4); also elsewhere on the board
COL11: U1.41 (PB5); also elsewhere on the board
COL12: U1.2 (PC13); also elsewhere on the board
COL13: U1.3 (PC14); also elsewhere on the board
COL14: U1.4 (PC15); also elsewhere on the board
D_N: U1.32 (PA11), U3.3 (D-O)
D_NI: U3.4 (D-I), USB1.5 (DN2), USB1.7 (DN1)
D_P: U1.33 (PA12), U3.1 (D+O)
D_PI: U3.6 (D+I), USB1.6 (DP1), USB1.8 (DP2)
GND: C1.2, C2.2, C3.2, C4.2, C5.2, C6.2, C7.2, C8.2, C9.2, C10.2, C11.2, J1.2, Q1.2 (E), RC6.1, RC7.1, RC8.2, U1.8 (VSSA), U1.23 (VSS), U1.35 (VSS), U1.47 (VSS), U2.2 (GND), U3.2 (SH_GND), USB1.1 (GND), USB1.12 (GND), USB1.13 (SHIELD), Y1.2, Y1.4; also elsewhere on the board
LEDGND: Q1.3 (C); also elsewhere on the board
LEDPWM: RC1.2, U1.45 (PB8)
NRST: C9.1, J1.4, U1.7 (NRST)
unnamed: Q1.1 (B), RC1.1
unnamed: RC6.2, USB1.4 (CC1)
unnamed: RC7.2, USB1.10 (CC2)
unnamed: RC8.1, SW1.2, U1.44 (BOOT0)
OSC_IN: C1.1, U1.5 (PF0), Y1.3
OSC_OUT: C2.1, U1.6 (PF1), Y1.1
RGBLED_3V3: U1.17 (PA7); also elsewhere on the board
ROW0: U1.29 (PA8); also elsewhere on the board
ROW1: U1.12 (PA2); also elsewhere on the board
ROW2: U1.26 (PB13); also elsewhere on the board
ROW3: U1.20 (PB2); also elsewhere on the board
ROW4: U1.21 (PB10); also elsewhere on the board
SWCLK: J1.3, U1.37 (PA14)
SWDIO: J1.1, U1.34 (PA13)
VCC: F1.2, USB1.2 (VBUS), USB1.11 (VBUS)

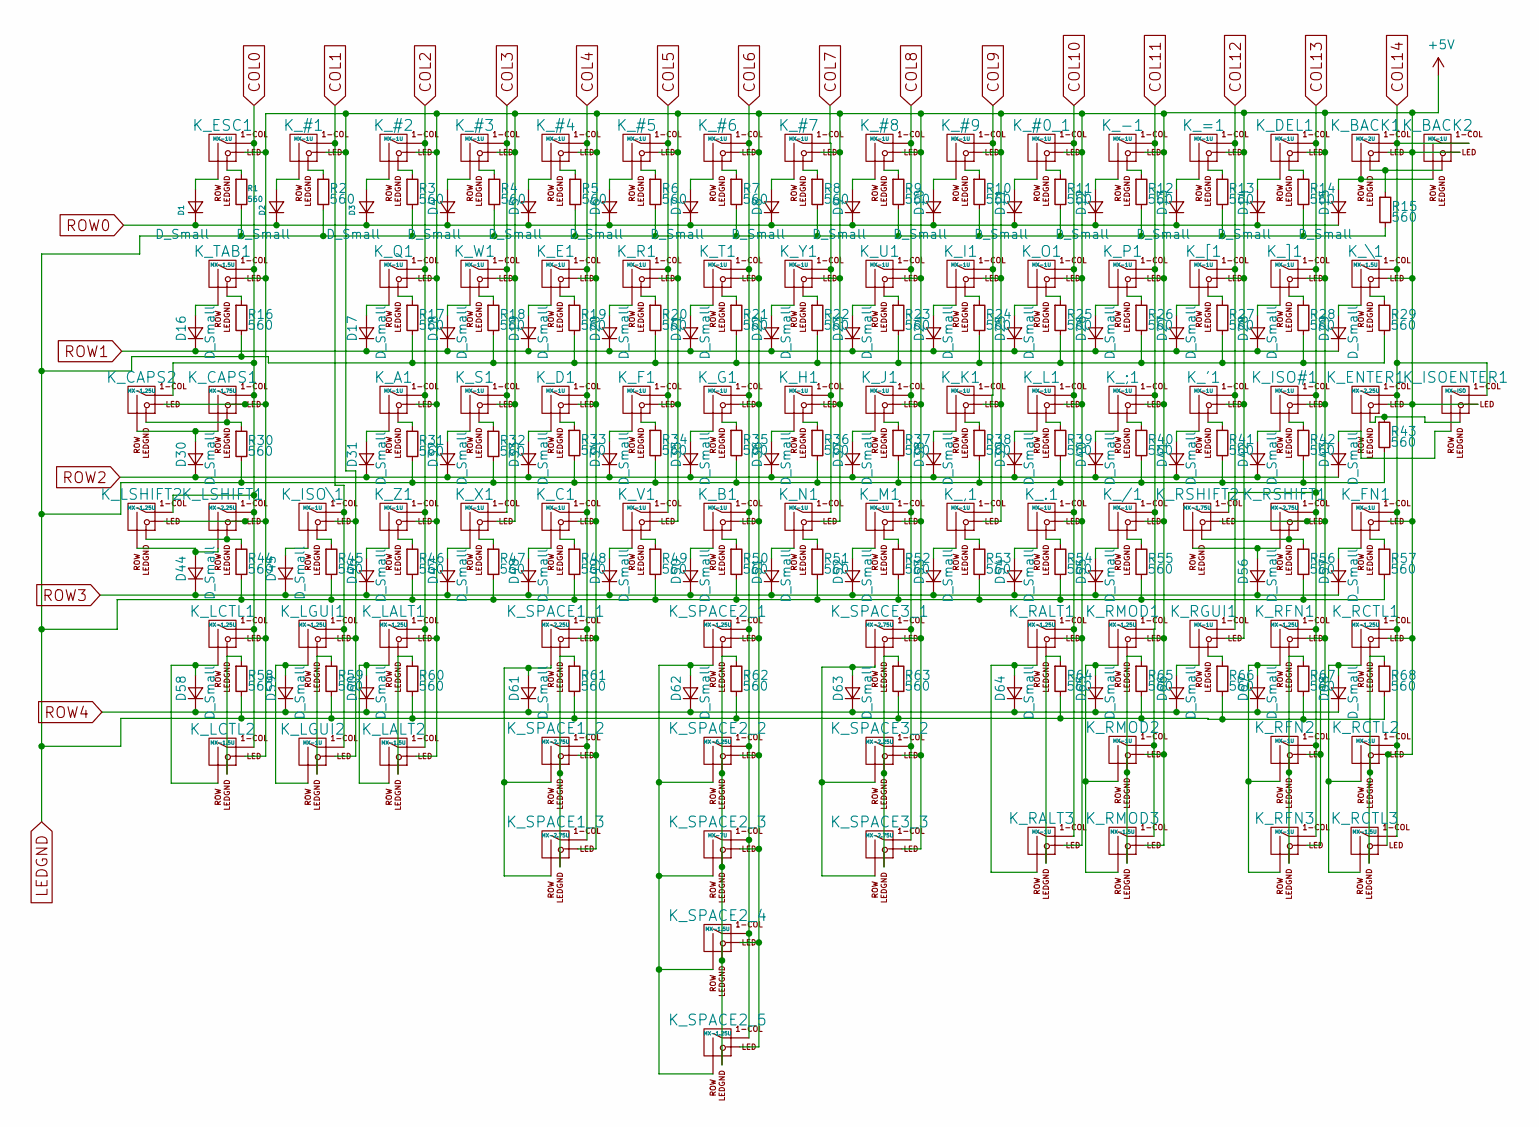
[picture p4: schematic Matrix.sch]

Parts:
D1: D_Small; D_SOD-123; Digi-Key_PN 1N4148WTPMSCT-ND
D2, D3, D4, D5, D6, D7, D8, D9, D10, D11, D12, D13, D14, D15, D16, D17, D18, D19, D20, D21, D22, D23, D24, D25, D26, D27, D28, D29, D30, D31, D32, D33, D34, D35, D36, D37, D38, D39, D40, D41, D42, D43, D44, D45, D46, D47, D48, D49, D50, D51, D52, D53, D54, D55, D56, D57, D58, D59, D60, D61, D62, D63, D64, D65, D66, D67, D68: D_Small; D_SOD-123
K_#0_1, K_#1, K_#2, K_#3, K_#4, K_#5, K_#6, K_#7, K_#8, K_#9: MX-1U; MXOnly-1U-FLIPPED
K_'1: MX-1U; MXOnly-1U-FLIPPED
K_,1: MX-1U; MXOnly-1U-FLIPPED
K_-1: MX-1U; MXOnly-1U-FLIPPED
K_.1: MX-1U; MXOnly-1U-FLIPPED
K_/1: MX-1U; MXOnly-1U-FLIPPED
K_;1: MX-1U; MXOnly-1U-FLIPPED
K_=1: MX-1U; MXOnly-1U-FLIPPED
K_A1: MX-1U; MXOnly-1U-FLIPPED
K_B1: MX-1U; MXOnly-1U-FLIPPED
K_BACK1: MX-2U; MXOnly-2U-FLIPPED
K_BACK2: MX-1U; MXOnly-1U-FLIPPED
K_C1: MX-1U; MXOnly-1U-FLIPPED
K_CAPS1: MX-1.75U; MXOnly-1.75U
K_CAPS2: MX-1.25U; MXOnly-1.25U-FLIPPED
K_D1: MX-1U; MXOnly-1U-FLIPPED
K_DEL1: MX-1U; MXOnly-1U-FLIPPED
K_E1: MX-1U; MXOnly-1U-FLIPPED
K_ENTER1: MX-2.25U; MXOnly-2.25U-FLIPPED
K_ESC1: MX-1U; MXOnly-1U-FLIPPED
K_F1: MX-1U; MXOnly-1U-FLIPPED
K_FN1: MX-1U; MXOnly-1U-FLIPPED
K_G1: MX-1U; MXOnly-1U-FLIPPED
K_H1: MX-1U; MXOnly-1U-FLIPPED
K_I1: MX-1U; MXOnly-1U-FLIPPED
K_ISO#1: MX-1U; MXOnly-1U-FLIPPED
K_ISOENTER1: MX-ISO; MXOnly-ISO-ROTATED-ReversedStabilizers
K_ISO\1: MX-1U; MXOnly-1U-FLIPPED
K_J1: MX-1U; MXOnly-1U-FLIPPED
K_K1: MX-1U; MXOnly-1U-FLIPPED
K_L1: MX-1U; MXOnly-1U-FLIPPED
K_LALT1: MX-1.25U; MXOnly-1.25U-FLIPPED
K_LALT2: MX-1.5U; MXOnly-1.5U
K_LCTL1: MX-1.25U; MXOnly-1.25U-FLIPPED
K_LCTL2: MX-1.5U; MXOnly-1.5U
K_LGUI1: MX-1.25U; MXOnly-1.25U-FLIPPED
K_LGUI2: MX-1U; MXOnly-1U
K_LSHIFT1: MX-2.25U; MXOnly-2.25U-FLIPPED
K_LSHIFT2: MX-1.25U; MXOnly-1.25U-FLIPPED
K_M1: MX-1U; MXOnly-1U-FLIPPED
K_N1: MX-1U; MXOnly-1U-FLIPPED
K_O1: MX-1U; MXOnly-1U-FLIPPED
K_P1: MX-1U; MXOnly-1U-FLIPPED
K_Q1: MX-1U; MXOnly-1U-FLIPPED
K_R1: MX-1U; MXOnly-1U-FLIPPED
K_RALT1: MX-1.25U; MXOnly-1.25U-FLIPPED
K_RALT3: MX-1U; MXOnly-1U
K_RCTL1: MX-1.25U; MXOnly-1.25U-FLIPPED
K_RCTL2: MX-1U; MXOnly-1U
K_RCTL3: MX-1.5U; MXOnly-1.5U
K_RFN1: MX-1.25U; MXOnly-1.25U-FLIPPED
K_RFN2, K_RFN3: MX-1U; MXOnly-1U
K_RGUI1: MX-1U; MXOnly-1U-FLIPPED
K_RMOD1: MX-1.25U; MXOnly-1.25U
K_RMOD2: MX-1U; MXOnly-1U
K_RMOD3: MX-1.5U; MXOnly-1.5U-FLIPPED
K_RSHIFT1: MX-2.75U; MXOnly-2.75U-FLIPPED
K_RSHIFT2: MX-1.75U; MXOnly-1.75U-FLIPPED
K_S1: MX-1U; MXOnly-1U-FLIPPED
K_SPACE1_1, K_SPACE3_2: MX-2.25U; MXOnly-2.25U-ReversedStabilizers
K_SPACE1_2, K_SPACE3_1: MX-2.75U; MXOnly-2.75U-FLIPPED-ReversedStabilizers
K_SPACE1_3, K_SPACE3_3: MX-2.75U; MXOnly-2.75U-ReversedStabilizers
K_SPACE2_1, K_SPACE2_5: MX-1.25U; MXOnly-1.25U-FLIPPED
K_SPACE2_2: MX-6.25U; MXOnly-6.25U-ReversedStabilizers
K_SPACE2_3: MX-7U; MXOnly-7U-ReversedStabilizers
K_SPACE2_4: MX-1.5U; MXOnly-1.5U
K_T1: MX-1U; MXOnly-1U-FLIPPED
K_TAB1: MX-1.5U; MXOnly-1.5U-FLIPPED
K_U1: MX-1U; MXOnly-1U-FLIPPED
K_V1: MX-1U; MXOnly-1U-FLIPPED
K_W1: MX-1U; MXOnly-1U-FLIPPED
K_X1: MX-1U; MXOnly-1U-FLIPPED
K_Y1: MX-1U; MXOnly-1U-FLIPPED
K_Z1: MX-1U; MXOnly-1U-FLIPPED
K_[1: MX-1U; MXOnly-1U-FLIPPED
K_\1: MX-1.5U; MXOnly-1.5U-FLIPPED
K_]1: MX-1U; MXOnly-1U-FLIPPED
R1: 560; R_0603; Digi-Key_PN MCT0603-560-CFCT-ND
R2, R3, R4, R5, R6, R7, R8, R9, R10, R11, R12, R13, R14, R15, R16, R17, R18, R19, R20, R21, R22, R23, R24, R25, R26, R27, R28, R29, R30, R31, R32, R33, R34, R35, R36, R37, R38, R39, R40, R41, R42, R43, R44, R45, R46, R47, R48, R49, R50, R51, R52, R53, R54, R55, R56, R57, R58, R59, R60, R61, R62, R63, R64, R65, R66, R67, R68: 560; R_0603

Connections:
+5V: K_#0_1.3 (LED), K_#1.3 (LED), K_#2.3 (LED), K_#3.3 (LED), K_#4.3 (LED), K_#5.3 (LED), K_#6.3 (LED), K_#7.3 (LED), K_#8.3 (LED), K_#9.3 (LED), K_'1.3 (LED), K_,1.3 (LED), K_-1.3 (LED), K_.1.3 (LED), K_/1.3 (LED), K_;1.3 (LED), K_=1.3 (LED), K_A1.3 (LED), K_B1.3 (LED), K_BACK1.3 (LED), K_BACK2.3 (LED), K_C1.3 (LED), K_CAPS1.3 (LED), K_CAPS2.3 (LED), K_D1.3 (LED), K_DEL1.3 (LED), K_E1.3 (LED), K_ENTER1.3 (LED), K_ESC1.3 (LED), K_F1.3 (LED), K_FN1.3 (LED), K_G1.3 (LED), K_H1.3 (LED), K_I1.3 (LED), K_ISO#1.3 (LED), K_ISOENTER1.3 (LED), K_ISO\1.3 (LED), K_J1.3 (LED), K_K1.3 (LED), K_L1.3 (LED), K_LALT1.3 (LED), K_LALT2.3 (LED), K_LCTL1.3 (LED), K_LCTL2.3 (LED), K_LGUI1.3 (LED), K_LGUI2.3 (LED), K_LSHIFT1.3 (LED), K_LSHIFT2.3 (LED), K_M1.3 (LED), K_N1.3 (LED), K_O1.3 (LED), K_P1.3 (LED), K_Q1.3 (LED), K_R1.3 (LED), K_RALT1.3 (LED), K_RALT3.3 (LED), K_RCTL1.3 (LED), K_RCTL2.3 (LED), K_RCTL3.3 (LED), K_RFN1.3 (LED), K_RFN2.3 (LED), K_RFN3.3 (LED), K_RGUI1.3 (LED), K_RMOD1.3 (LED), K_RMOD2.3 (LED), K_RMOD3.3 (LED), K_RSHIFT1.3 (LED), K_RSHIFT2.3 (LED), K_S1.3 (LED), K_SPACE1_1.3 (LED), K_SPACE1_2.3 (LED), K_SPACE1_3.3 (LED), K_SPACE2_1.3 (LED), K_SPACE2_2.3 (LED), K_SPACE2_3.3 (LED), K_SPACE2_4.3 (LED), K_SPACE2_5.3 (LED), K_SPACE3_1.3 (LED), K_SPACE3_2.3 (LED), K_SPACE3_3.3 (LED), K_T1.3 (LED), K_TAB1.3 (LED), K_U1.3 (LED), K_V1.3 (LED), K_W1.3 (LED), K_X1.3 (LED), K_Y1.3 (LED), K_Z1.3 (LED), K_[1.3 (LED), K_\1.3 (LED), K_]1.3 (LED); also elsewhere on the board
COL0: K_CAPS1.1 (COL), K_CAPS2.1 (COL), K_ESC1.1 (COL), K_LCTL1.1 (COL), K_LCTL2.1 (COL), K_LSHIFT1.1 (COL), K_LSHIFT2.1 (COL), K_TAB1.1 (COL); also elsewhere on the board
COL1: K_#1.1 (COL), K_ISO\1.1 (COL), K_LGUI1.1 (COL), K_LGUI2.1 (COL); also elsewhere on the board
COL2: K_#2.1 (COL), K_A1.1 (COL), K_LALT1.1 (COL), K_LALT2.1 (COL), K_Q1.1 (COL), K_Z1.1 (COL); also elsewhere on the board
COL3: K_#3.1 (COL), K_S1.1 (COL), K_W1.1 (COL), K_X1.1 (COL); also elsewhere on the board
COL4: K_#4.1 (COL), K_C1.1 (COL), K_D1.1 (COL), K_E1.1 (COL), K_SPACE1_1.1 (COL), K_SPACE1_2.1 (COL), K_SPACE1_3.1 (COL); also elsewhere on the board
COL5: K_#5.1 (COL), K_F1.1 (COL), K_R1.1 (COL), K_V1.1 (COL); also elsewhere on the board
COL6: K_#6.1 (COL), K_B1.1 (COL), K_G1.1 (COL), K_SPACE2_1.1 (COL), K_SPACE2_2.1 (COL), K_SPACE2_3.1 (COL), K_SPACE2_4.1 (COL), K_SPACE2_5.1 (COL), K_T1.1 (COL); also elsewhere on the board
COL7: K_#7.1 (COL), K_H1.1 (COL), K_N1.1 (COL), K_Y1.1 (COL); also elsewhere on the board
COL8: K_#8.1 (COL), K_J1.1 (COL), K_M1.1 (COL), K_SPACE3_1.1 (COL), K_SPACE3_2.1 (COL), K_SPACE3_3.1 (COL), K_U1.1 (COL); also elsewhere on the board
COL9: K_#9.1 (COL), K_,1.1 (COL), K_I1.1 (COL), K_K1.1 (COL); also elsewhere on the board
COL10: K_#0_1.1 (COL), K_.1.1 (COL), K_L1.1 (COL), K_O1.1 (COL), K_RALT1.1 (COL), K_RALT3.1 (COL); also elsewhere on the board
COL11: K_-1.1 (COL), K_/1.1 (COL), K_;1.1 (COL), K_P1.1 (COL), K_RMOD1.1 (COL), K_RMOD2.1 (COL), K_RMOD3.1 (COL); also elsewhere on the board
COL12: K_'1.1 (COL), K_=1.1 (COL), K_RGUI1.1 (COL), K_[1.1 (COL); also elsewhere on the board
COL13: K_DEL1.1 (COL), K_ISO#1.1 (COL), K_RFN1.1 (COL), K_RFN2.1 (COL), K_RFN3.1 (COL), K_RSHIFT1.1 (COL), K_RSHIFT2.1 (COL), K_]1.1 (COL); also elsewhere on the board
COL14: K_BACK1.1 (COL), K_BACK2.1 (COL), K_ENTER1.1 (COL), K_FN1.1 (COL), K_ISOENTER1.1 (COL), K_RCTL1.1 (COL), K_RCTL2.1 (COL), K_RCTL3.1 (COL), K_\1.1 (COL); also elsewhere on the board
LEDGND: R1.2, R2.2, R3.2, R4.2, R5.2, R6.2, R7.2, R8.2, R9.2, R10.2, R11.2, R12.2, R13.2, R14.2, R15.2, R16.2, R17.2, R18.2, R19.2, R20.2, R21.2, R22.2, R23.2, R24.2, R25.2, R26.2, R27.2, R28.2, R29.2, R30.2, R31.2, R32.2, R33.2, R34.2, R35.2, R36.2, R37.2, R38.2, R39.2, R40.2, R41.2, R42.2, R43.2, R44.2, R45.2, R46.2, R47.2, R48.2, R49.2, R50.2, R51.2, R52.2, R53.2, R54.2, R55.2, R56.2, R57.2, R58.2, R59.2, R60.2, R61.2, R62.2, R63.2, R64.2, R65.2, R66.2, R67.2, R68.2; also elsewhere on the board
unnamed: D1.2 (A), K_ESC1.2 (ROW)
unnamed: D2.2 (A), K_#1.2 (ROW)
unnamed: D3.2 (A), K_#2.2 (ROW)
unnamed: D4.2 (A), K_#3.2 (ROW)
unnamed: D5.2 (A), K_#4.2 (ROW)
unnamed: D6.2 (A), K_#5.2 (ROW)
unnamed: D7.2 (A), K_#6.2 (ROW)
unnamed: D8.2 (A), K_#7.2 (ROW)
unnamed: D9.2 (A), K_#8.2 (ROW)
unnamed: D10.2 (A), K_#9.2 (ROW)
unnamed: D11.2 (A), K_#0_1.2 (ROW)
unnamed: D12.2 (A), K_-1.2 (ROW)
unnamed: D13.2 (A), K_=1.2 (ROW)
unnamed: D14.2 (A), K_DEL1.2 (ROW)
unnamed: D15.2 (A), K_BACK1.2 (ROW), K_BACK2.2 (ROW)
unnamed: D16.2 (A), K_TAB1.2 (ROW)
unnamed: D17.2 (A), K_Q1.2 (ROW)
unnamed: D18.2 (A), K_W1.2 (ROW)
unnamed: D19.2 (A), K_E1.2 (ROW)
unnamed: D20.2 (A), K_R1.2 (ROW)
unnamed: D21.2 (A), K_T1.2 (ROW)
unnamed: D22.2 (A), K_Y1.2 (ROW)
unnamed: D23.2 (A), K_U1.2 (ROW)
unnamed: D24.2 (A), K_I1.2 (ROW)
unnamed: D25.2 (A), K_O1.2 (ROW)
unnamed: D26.2 (A), K_P1.2 (ROW)
unnamed: D27.2 (A), K_[1.2 (ROW)
unnamed: D28.2 (A), K_]1.2 (ROW)
unnamed: D29.2 (A), K_\1.2 (ROW)
unnamed: D30.2 (A), K_CAPS1.2 (ROW), K_CAPS2.2 (ROW)
unnamed: D31.2 (A), K_A1.2 (ROW)
unnamed: D32.2 (A), K_S1.2 (ROW)
unnamed: D33.2 (A), K_D1.2 (ROW)
unnamed: D34.2 (A), K_F1.2 (ROW)
unnamed: D35.2 (A), K_G1.2 (ROW)
unnamed: D36.2 (A), K_H1.2 (ROW)
unnamed: D37.2 (A), K_J1.2 (ROW)
unnamed: D38.2 (A), K_K1.2 (ROW)
unnamed: D39.2 (A), K_L1.2 (ROW)
unnamed: D40.2 (A), K_;1.2 (ROW)
unnamed: D41.2 (A), K_'1.2 (ROW)
unnamed: D42.2 (A), K_ISO#1.2 (ROW)
unnamed: D43.2 (A), K_ENTER1.2 (ROW), K_ISOENTER1.2 (ROW)
unnamed: D44.2 (A), K_LSHIFT1.2 (ROW), K_LSHIFT2.2 (ROW)
unnamed: D45.2 (A), K_ISO\1.2 (ROW)
unnamed: D46.2 (A), K_Z1.2 (ROW)
unnamed: D47.2 (A), K_X1.2 (ROW)
unnamed: D48.2 (A), K_C1.2 (ROW)
unnamed: D49.2 (A), K_V1.2 (ROW)
unnamed: D50.2 (A), K_B1.2 (ROW)
unnamed: D51.2 (A), K_N1.2 (ROW)
unnamed: D52.2 (A), K_M1.2 (ROW)
unnamed: D53.2 (A), K_,1.2 (ROW)
unnamed: D54.2 (A), K_.1.2 (ROW)
unnamed: D55.2 (A), K_/1.2 (ROW)
unnamed: D56.2 (A), K_RSHIFT1.2 (ROW), K_RSHIFT2.2 (ROW)
unnamed: D57.2 (A), K_FN1.2 (ROW)
unnamed: D58.2 (A), K_LCTL1.2 (ROW), K_LCTL2.2 (ROW)
unnamed: D59.2 (A), K_LGUI1.2 (ROW), K_LGUI2.2 (ROW)
unnamed: D60.2 (A), K_LALT1.2 (ROW), K_LALT2.2 (ROW)
unnamed: D61.2 (A), K_SPACE1_1.2 (ROW), K_SPACE1_2.2 (ROW), K_SPACE1_3.2 (ROW)
unnamed: D62.2 (A), K_SPACE2_1.2 (ROW), K_SPACE2_2.2 (ROW), K_SPACE2_3.2 (ROW), K_SPACE2_4.2 (ROW), K_SPACE2_5.2 (ROW)
unnamed: D63.2 (A), K_SPACE3_1.2 (ROW), K_SPACE3_2.2 (ROW), K_SPACE3_3.2 (ROW)
unnamed: D64.2 (A), K_RALT1.2 (ROW), K_RALT3.2 (ROW)
unnamed: D65.2 (A), K_RMOD1.2 (ROW), K_RMOD2.2 (ROW), K_RMOD3.2 (ROW)
unnamed: D66.2 (A), K_RGUI1.2 (ROW)
unnamed: D67.2 (A), K_RFN1.2 (ROW), K_RFN2.2 (ROW), K_RFN3.2 (ROW)
unnamed: D68.2 (A), K_RCTL1.2 (ROW), K_RCTL2.2 (ROW), K_RCTL3.2 (ROW)
unnamed: K_#0_1.4 (LEDGND), R11.1
unnamed: K_#1.4 (LEDGND), R2.1
unnamed: K_#2.4 (LEDGND), R3.1
unnamed: K_#3.4 (LEDGND), R4.1
unnamed: K_#4.4 (LEDGND), R5.1
unnamed: K_#5.4 (LEDGND), R6.1
unnamed: K_#6.4 (LEDGND), R7.1
unnamed: K_#7.4 (LEDGND), R8.1
unnamed: K_#8.4 (LEDGND), R9.1
unnamed: K_#9.4 (LEDGND), R10.1
unnamed: K_'1.4 (LEDGND), R41.1
unnamed: K_,1.4 (LEDGND), R53.1
unnamed: K_-1.4 (LEDGND), R12.1
unnamed: K_.1.4 (LEDGND), R54.1
unnamed: K_/1.4 (LEDGND), R55.1
unnamed: K_;1.4 (LEDGND), R40.1
unnamed: K_=1.4 (LEDGND), R13.1
unnamed: K_A1.4 (LEDGND), R31.1
unnamed: K_B1.4 (LEDGND), R50.1
unnamed: K_BACK1.4 (LEDGND), K_BACK2.4 (LEDGND), R15.1
unnamed: K_C1.4 (LEDGND), R48.1
unnamed: K_CAPS1.4 (LEDGND), K_CAPS2.4 (LEDGND), R30.1
unnamed: K_D1.4 (LEDGND), R33.1
unnamed: K_DEL1.4 (LEDGND), R14.1
unnamed: K_E1.4 (LEDGND), R19.1
unnamed: K_ENTER1.4 (LEDGND), K_ISOENTER1.4 (LEDGND), R43.1
unnamed: K_ESC1.4 (LEDGND), R1.1
unnamed: K_F1.4 (LEDGND), R34.1
unnamed: K_FN1.4 (LEDGND), R57.1
unnamed: K_G1.4 (LEDGND), R35.1
unnamed: K_H1.4 (LEDGND), R36.1
unnamed: K_I1.4 (LEDGND), R24.1
unnamed: K_ISO#1.4 (LEDGND), R42.1
unnamed: K_ISO\1.4 (LEDGND), R45.1
unnamed: K_J1.4 (LEDGND), R37.1
unnamed: K_K1.4 (LEDGND), R38.1
unnamed: K_L1.4 (LEDGND), R39.1
unnamed: K_LALT1.4 (LEDGND), K_LALT2.4 (LEDGND), R60.1
unnamed: K_LCTL1.4 (LEDGND), K_LCTL2.4 (LEDGND), R58.1
unnamed: K_LGUI1.4 (LEDGND), K_LGUI2.4 (LEDGND), R59.1
unnamed: K_LSHIFT1.4 (LEDGND), K_LSHIFT2.4 (LEDGND), R44.1
unnamed: K_M1.4 (LEDGND), R52.1
unnamed: K_N1.4 (LEDGND), R51.1
unnamed: K_O1.4 (LEDGND), R25.1
unnamed: K_P1.4 (LEDGND), R26.1
unnamed: K_Q1.4 (LEDGND), R17.1
unnamed: K_R1.4 (LEDGND), R20.1
unnamed: K_RALT1.4 (LEDGND), K_RALT3.4 (LEDGND), R64.1
unnamed: K_RCTL1.4 (LEDGND), K_RCTL2.4 (LEDGND), K_RCTL3.4 (LEDGND), R68.1
unnamed: K_RFN1.4 (LEDGND), K_RFN2.4 (LEDGND), K_RFN3.4 (LEDGND), R67.1
unnamed: K_RGUI1.4 (LEDGND), R66.1
unnamed: K_RMOD1.4 (LEDGND), K_RMOD2.4 (LEDGND), K_RMOD3.4 (LEDGND), R65.1
unnamed: K_RSHIFT1.4 (LEDGND), K_RSHIFT2.4 (LEDGND), R56.1
unnamed: K_S1.4 (LEDGND), R32.1
unnamed: K_SPACE1_1.4 (LEDGND), K_SPACE1_2.4 (LEDGND), K_SPACE1_3.4 (LEDGND), R61.1
unnamed: K_SPACE2_1.4 (LEDGND), K_SPACE2_2.4 (LEDGND), K_SPACE2_3.4 (LEDGND), K_SPACE2_4.4 (LEDGND), K_SPACE2_5.4 (LEDGND), R62.1
unnamed: K_SPACE3_1.4 (LEDGND), K_SPACE3_2.4 (LEDGND), K_SPACE3_3.4 (LEDGND), R63.1
unnamed: K_T1.4 (LEDGND), R21.1
unnamed: K_TAB1.4 (LEDGND), R16.1
unnamed: K_U1.4 (LEDGND), R23.1
unnamed: K_V1.4 (LEDGND), R49.1
unnamed: K_W1.4 (LEDGND), R18.1
unnamed: K_X1.4 (LEDGND), R47.1
unnamed: K_Y1.4 (LEDGND), R22.1
unnamed: K_Z1.4 (LEDGND), R46.1
unnamed: K_[1.4 (LEDGND), R27.1
unnamed: K_\1.4 (LEDGND), R29.1
unnamed: K_]1.4 (LEDGND), R28.1
ROW0: D1.1 (K), D2.1 (K), D3.1 (K), D4.1 (K), D5.1 (K), D6.1 (K), D7.1 (K), D8.1 (K), D9.1 (K), D10.1 (K), D11.1 (K), D12.1 (K), D13.1 (K), D14.1 (K), D15.1 (K); also elsewhere on the board
ROW1: D16.1 (K), D17.1 (K), D18.1 (K), D19.1 (K), D20.1 (K), D21.1 (K), D22.1 (K), D23.1 (K), D24.1 (K), D25.1 (K), D26.1 (K), D27.1 (K), D28.1 (K), D29.1 (K); also elsewhere on the board
ROW2: D30.1 (K), D31.1 (K), D32.1 (K), D33.1 (K), D34.1 (K), D35.1 (K), D36.1 (K), D37.1 (K), D38.1 (K), D39.1 (K), D40.1 (K), D41.1 (K), D42.1 (K), D43.1 (K); also elsewhere on the board
ROW3: D44.1 (K), D45.1 (K), D46.1 (K), D47.1 (K), D48.1 (K), D49.1 (K), D50.1 (K), D51.1 (K), D52.1 (K), D53.1 (K), D54.1 (K), D55.1 (K), D56.1 (K), D57.1 (K); also elsewhere on the board
ROW4: D58.1 (K), D59.1 (K), D60.1 (K), D61.1 (K), D62.1 (K), D63.1 (K), D64.1 (K), D65.1 (K), D66.1 (K), D67.1 (K), D68.1 (K); also elsewhere on the board

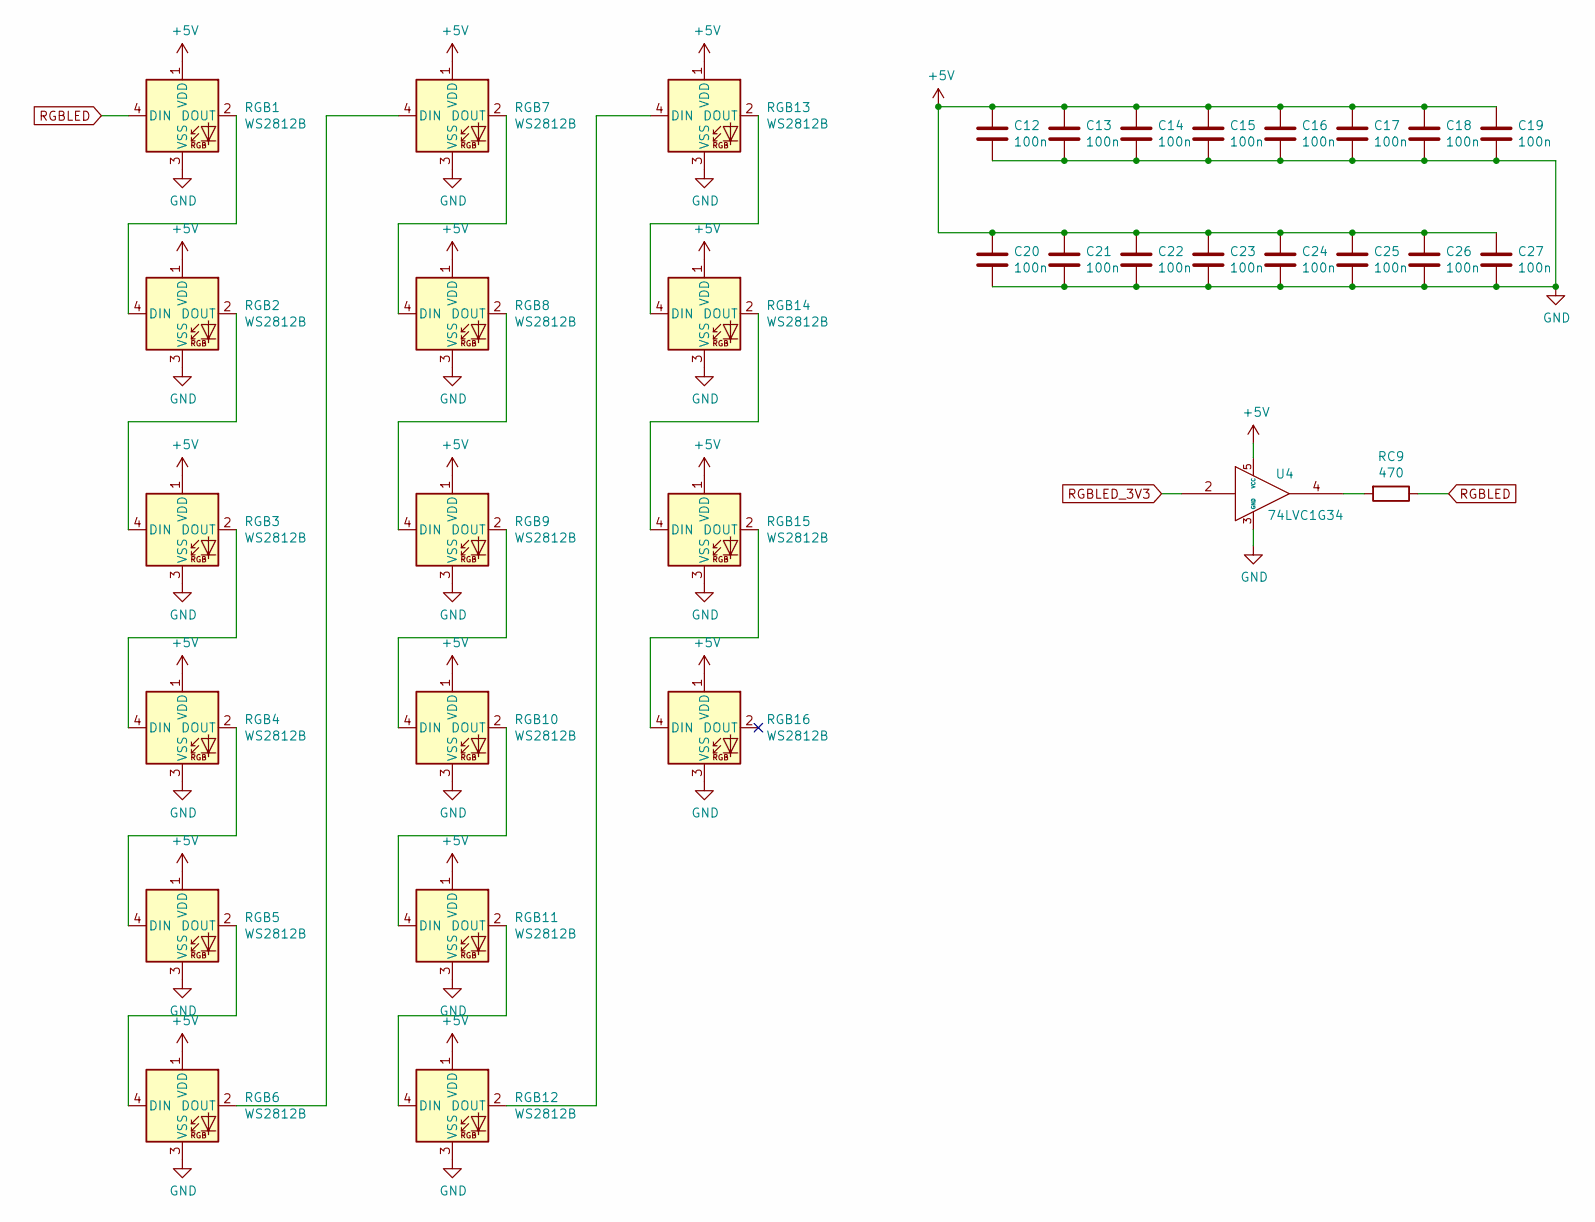
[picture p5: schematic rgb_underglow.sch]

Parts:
C12, C13, C14, C15, C16, C17, C18, C19, C20, C21, C22, C23, C24, C25, C26, C27: 100n; C_0603_1608Metric; LCSC PN C1590
RC9: 470; R_0603_1608Metric; LCSC PN C114433
RGB1, RGB2, RGB3, RGB4, RGB5, RGB6, RGB7, RGB8, RGB9, RGB10, RGB11, RGB12, RGB13, RGB14, RGB15, RGB16: WS2812B; LED_WS2812B_PLCC4_5.0x5.0mm_P3.2mm; LCSC PN C114585
U4: 74LVC1G34; SOT-353_SC-70-5; LCSC PN C94111

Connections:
+5V: C12.1, C13.1, C14.1, C15.1, C16.1, C17.1, C18.1, C19.1, C20.1, C21.1, C22.1, C23.1, C24.1, C25.1, C26.1, C27.1, RGB1.1 (VDD), RGB2.1 (VDD), RGB3.1 (VDD), RGB4.1 (VDD), RGB5.1 (VDD), RGB6.1 (VDD), RGB7.1 (VDD), RGB8.1 (VDD), RGB9.1 (VDD), RGB10.1 (VDD), RGB11.1 (VDD), RGB12.1 (VDD), RGB13.1 (VDD), RGB14.1 (VDD), RGB15.1 (VDD), RGB16.1 (VDD), U4.5 (VCC); also elsewhere on the board
GND: C12.2, C13.2, C14.2, C15.2, C16.2, C17.2, C18.2, C19.2, C20.2, C21.2, C22.2, C23.2, C24.2, C25.2, C26.2, C27.2, RGB1.3 (VSS), RGB2.3 (VSS), RGB3.3 (VSS), RGB4.3 (VSS), RGB5.3 (VSS), RGB6.3 (VSS), RGB7.3 (VSS), RGB8.3 (VSS), RGB9.3 (VSS), RGB10.3 (VSS), RGB11.3 (VSS), RGB12.3 (VSS), RGB13.3 (VSS), RGB14.3 (VSS), RGB15.3 (VSS), RGB16.3 (VSS), U4.3 (GND); also elsewhere on the board
unnamed: RC9.2, U4.4
unnamed: RGB1.2 (DOUT), RGB2.4 (DIN)
unnamed: RGB2.2 (DOUT), RGB3.4 (DIN)
unnamed: RGB3.2 (DOUT), RGB4.4 (DIN)
unnamed: RGB4.2 (DOUT), RGB5.4 (DIN)
unnamed: RGB5.2 (DOUT), RGB6.4 (DIN)
unnamed: RGB6.2 (DOUT), RGB7.4 (DIN)
unnamed: RGB7.2 (DOUT), RGB8.4 (DIN)
unnamed: RGB8.2 (DOUT), RGB9.4 (DIN)
unnamed: RGB10.2 (DOUT), RGB11.4 (DIN)
unnamed: RGB9.2 (DOUT), RGB10.4 (DIN)
unnamed: RGB11.2 (DOUT), RGB12.4 (DIN)
unnamed: RGB12.2 (DOUT), RGB13.4 (DIN)
unnamed: RGB13.2 (DOUT), RGB14.4 (DIN)
unnamed: RGB14.2 (DOUT), RGB15.4 (DIN)
unnamed: RGB15.2 (DOUT), RGB16.4 (DIN)
RGBLED: RC9.1, RGB1.4 (DIN)
RGBLED_3V3: U4.2; also elsewhere on the board

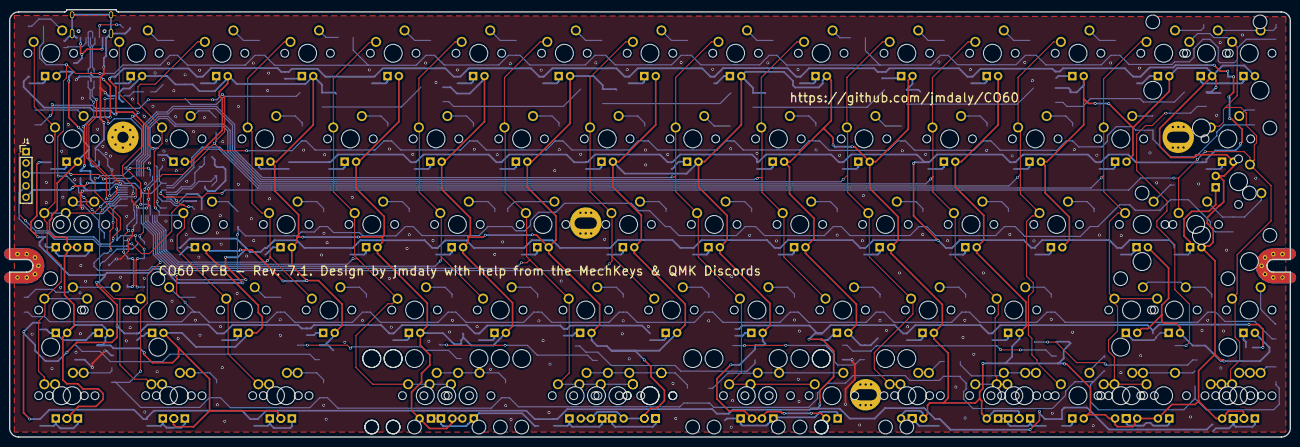
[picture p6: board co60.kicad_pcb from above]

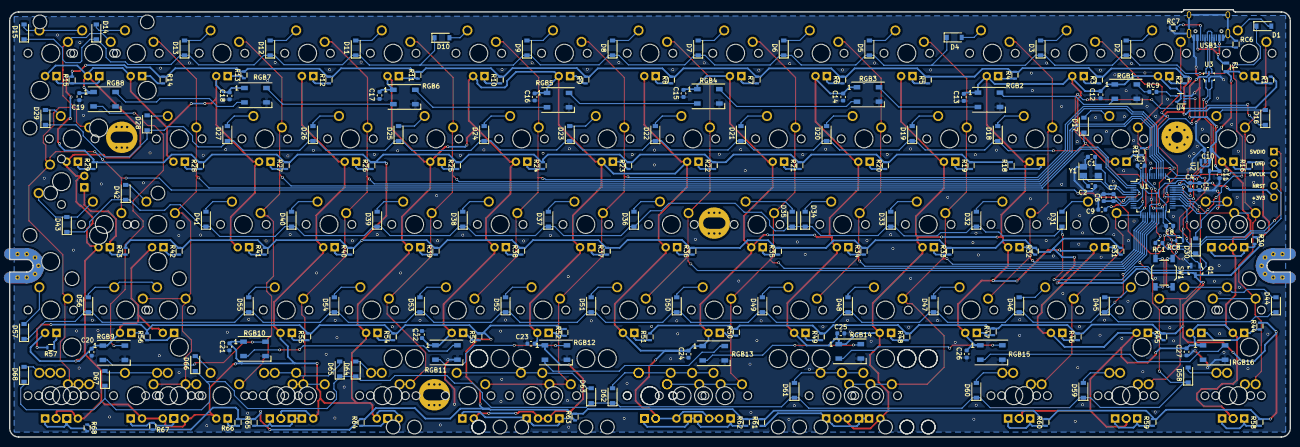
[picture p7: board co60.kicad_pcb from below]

Board: 2 copper layers, 285.0 x 95.1 mm, 285 parts (193 on the bottom side), 193 nets.

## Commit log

2018-03-25 Add: Initial commit of CO60 work
    There is much more work to do, the design is nowhere
    near finished
    [Matrix.sch, co60.kicad_pcb, co60.sch]
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2018-03-30 Update: More work on schematic connections. Not finished yet
    [Matrix.sch, co60.sch]
2018-04-02 Fix schematic errors, add datasheet links, and transistor for LEDs
    [Matrix.sch, co60.sch]
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2018-04-10 Update: Finish assigning footprints, and switch crystals
    I had been using the crystal that the GH60 uses, but it looked
    like it might be hard to source. Also, some of the bottom row
    footprints might need to be reversed, depending on the overlap
    of the switches.
    [Matrix.sch, co60.sch]
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2018-04-18 Update: Switch most of remaining switches to MX-only
    There isn't an MX-only footprint for ISO enter, so that one
    is still MX and Alps. When I have a chance, I'll make an MX-only
    version of it.
    [Matrix.sch, co60.kicad_pcb]
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2018-04-21 Update: Simplify right shift, fix footprint errors, layout switches
    [Matrix.sch, co60.kicad_pcb]
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2018-04-21 Update: Fix power connections
    [Matrix.sch, co60.sch]
2018-04-21 Update: Fix connections for fuses
    [co60.kicad_pcb]
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2018-04-22 Update: Work on moving resistors in schematic. Not done yet.
    I've got the top three rows done so far.
    [Matrix.sch]
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2018-04-27 Update: Switch to Amphenol USB C connector
    This connector seems more readily available than the Wurth,
    and is about half the price.
    [Matrix.sch, co60.kicad_pcb, co60.sch]
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2018-04-29 Update: Choose more components, lock switch footprints, place some resistors and diodes
    [Matrix.sch, co60.kicad_pcb]
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2018-05-01 Update: Flip LED orientation on most switch footprints
    I'm hoping this will separate the diodes and resistors
    a little more and make routing easier.
    [Matrix.sch, co60.kicad_pcb]
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2018-05-04 Update: Switch transistor to something smaller
    I don't think I needed a transistor as big as I had for the
    LEDs. I've switched to a SOT-23 footprint BJT that can
    dissipate 500 mW. This should be more than enough for
    68 LEDs at 5 mA each.
    [Matrix.sch, co60.kicad_pcb, co60.sch]
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2018-05-05 Update: Reverse crystal connections
    I'm not sure if this matters or not, but it seems
    consistent with the way the GH60 does it.
    [co60.kicad_pcb, co60.sch]
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2018-05-08 Update: More routing and fix a schematic mistake
    [Matrix.sch, co60.kicad_pcb]
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2018-05-10 Update: More routing. I think the switch matrix is all routed now
    [co60.kicad_pcb]
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2018-05-11 Fix: Work on pcbnew design rules violations
    [co60.kicad_pcb]
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2018-05-13 Fix: Connect all unconnected nets
    [co60.kicad_pcb]
2018-05-13 Fix: Connect the last unconnected net
    [co60.kicad_pcb]
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2018-05-14 Update: Temporarily increase my net clearance values, and re-routing
    I noticed in some other designs that the traces were farther
    from drill holes and pads than I was putting mine, so I
    figured I'd change that. I'm temporarily increasing
    my clearance to 0.35 (from 0.2032) and I'm using the
    OpenGL router to move my traces farther from holes and
    pads. I'll put my clearance back when I'm done. The next switch
    to adjust is K_#8
    [co60.kicad_pcb]
2018-05-14 Update: More routing adjustments to increase clearances
    [co60.kicad_pcb]
2018-05-15 Update: Move more tracks to increase clearance
    [co60.kicad_pcb]
2018-05-16 Update: More work on increasing clearances
    [co60.kicad_pcb]
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2018-05-16 Update: Move some more traces, and some component text on silk screen
    [co60.kicad_pcb]
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2018-05-20 Fix: Make keepout area around MCU consistent in size
    [co60.kicad_pcb]
2018-05-20 Fix: Increase width of an LED track
    [co60.kicad_pcb]
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2018-05-23 Update: Change board footprint to one with more room for Type-C
    Also clean up some routing
    [co60.kicad_pcb]
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2018-05-23 Update: Move diode to be consistent with other boards
    The DZ60 has a mounting hole where this diode was. So, to ensure
    compatibility with cases that support the DZ60, I moved the diode.
    [co60.kicad_pcb]
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2018-05-25 Add: Fields for components that shouldn't be part of the BOM
    This ensures that all of the switches won't be added as BOM
    lines.
    [Matrix.sch, co60.sch]
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2018-05-26 Update: README wording and formatted BOM so it can be parsedby github
    [co60_BOM_.csv]
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2018-06-05 Update: Re-route ground traces on USB connector
    After I moved it, I want to ensure that the actual connections
    are still in place.
    [co60-B.Cu.gbl, co60-B.Mask.gbs, co60-B.Paste.gbp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]
2018-06-07 Fix: Ensure no extra ground traces are travelling between ground planes
    On the Rev. 1 PCB, I noticed that I had ground traces running across my
    keepout area for the ground planes, effectively connecting the two
    ground planes (MCU/crystal and rest of the board) at additional
    locations. This commit fixes that. I also moved some traces to get
    better ground plane fill at other spots on the board.
    [co60.kicad_pcb]
2018-06-07 Fix: Increase width of VCC trace that was too thin
    [co60.kicad_pcb]
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2018-06-08 Fix: Move some silk screen values around so they don't get cut off
    [co60-B.Cu.gbl, co60-B.Mask.gbs, co60-B.Paste.gbp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]
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2018-06-13 Update: gerbers use the auxilliary axis set by drill and place offset
    [co60-B.Cu.gbl, co60-B.Mask.gbs, co60-B.Paste.gbp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]
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2018-06-14 Update: Move D4 and D10
    When I looked at the DZ60, it had mount holes where I had the D4 and
    D10 diodes. I figured this means there might be some cases that my
    placement would conflict with. I moved those two diodes to prevent
    any potential conflicts.
    [co60-B.Cu.gbl, co60-B.Mask.gbs, co60-B.Paste.gbp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]
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2018-06-18 Update: Move C1 and C2 to give a little more room around the crystal
    I want to make sure that, during assembly, the capacitors won't
    physically interfere with the crystal, so I moved them out a bit.
    [co60-B.Cu.gbl, co60-B.Mask.gbs, co60-B.Paste.gbp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]
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2018-07-10 Fix: Transistor base and emitter pin assignments were flipped
    In the inital version of the digikey footprint library that I
    was using, the pin assignments were wrong on the transistor
    schematic. This lead me to wiring up the emitter to where the
    base was supposed to go and vice versa. As a result, backlighting
    will not work on any revision of the board prior to this commit.
    This commit updates the digikey library, which has the fixed
    pin assignments, and re-routes the transistor pads correctly.
    [CO60-PCBA-Quotation.xlsx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]
2018-07-23 Update: Change silk screen to reflect new rev
    This is in preparation for the next production run, which will hopefully
    have the backlighting issue fixed. Gerbers have all been re-generated as
    well.
    [co60-B.Cu.gbl, co60-B.Mask.gbs, co60-B.Paste.gbp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]
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2018-08-31 Update: Switch USB connector from Amphenol to Korean HRO
    This connector is smaller, and I believe it will interfere less with the
    switches when they are installed.
    [co60-B.Cu.gbl, co60-B.Mask.gbs, co60-B.Paste.gbp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]
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2018-09-05 Fix: USB port also set as SMD component
    [co60.kicad_pcb]
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2018-09-15 Update: HRO connector to newest footprint version
    This version has solder pads for the through hole legs,
    which are necessary when doing PCB assembly.
    [co60-B.Cu.gbl, co60-B.Mask.gbs, co60-B.Paste.gbp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]
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2018-09-22 Update: Set HRO USB connector as surface mount component
    This ensures it appears in the placement file
    [co60-B.Cu.gbl, co60-B.Mask.gbs, co60-B.Paste.gbp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]
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2018-10-30 Update: Initial work on switching to STM32
    The schematic is complete, though may need revising.
    The PCB components need to be placed and routed.
    [Matrix.sch, co60.kicad_pcb, co60.sch]
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2018-10-30 Add: 47 pF caps on USB line for EMI filtering
    [co60-B.Cu.gbl, co60-B.Mask.gbs, co60-B.Paste.gbp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]
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2018-11-01 Update: Switch transistor base resitor to accomodate 3.3V
    Since the STM32 GPIO pins will output at 3.3V, we need to lower the
    resistor value at the transistor base pin so that the base will
    be supplied with enough current to keep the transistor in saturation.
    [co60-B.Cu.gbl, co60-B.Mask.gbs, co60-B.Paste.gbp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]
2018-11-05 Fix: Swap positions of C4 and C5 so they're in the correct spots
    [co60.kicad_pcb]
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2018-11-08 Update: Use NUF2221W1T2 for ESD protection and USB line termination
    This chip takes the place of six components that would otherwise need
    to be used (ESD protection chip, 2 caps for filtering, 2 22 Ohm
    resistors, and 1 1.5k Ohm pull up resistor)
    [co60-B.Cu.gbl, co60-B.Mask.gbs, co60-B.Paste.gbp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]
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2018-11-14 Update: Switch crystal pins to be consisten with reference designs
    I'm not sure if this is necessary or not, but in the reference designs I
    consulted, pin one of the crystal connects to OSCOUT on the MCU, so I
    decided to connect mine that way.
    [co60-B.Cu.gbl, co60-B.Mask.gbs, co60-B.Paste.gbp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]
2018-11-15 Update: Move linear reg decoupling cap further from MCU caps
    It was pointed out to me that it was unusual to have all those caps so
    close together. As a result, I tried moving the linear regulator one a
    bit in order to give them more separation.
    [co60-B.Cu.gbl, co60-B.Mask.gbs, co60-B.Paste.gbp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]
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2018-11-19 Fix: Ensure that ESD protection circuit is set to SMD
    [co60.kicad_pcb]
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2019-01-17 Update: Move RGB data pin from B15 to A7
    Upas' RGB work requires a pin with SPI MOSI, like B15 and A7. But Jack
    Humber's RGB work requires a pin whose number is less than 8. As a
    result, A7 seems like a good compromise.
    [co60.kicad_pcb, co60.sch]
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2019-01-17 Update: Add missing LCSC part numbers
    [co60-B.Cu.gbl, co60-B.Mask.gbs, co60-B.Paste.gbp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]
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2019-01-17 Update: Switch voltage level shifter to different component
    The initial component is out of stock at LCSC, so I found something that
    I believe is similar, but is more readily available.
    [co60-B.Cu.gbl, co60-B.Mask.gbs, co60-B.Paste.gbp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]
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2020-02-07 Upgrade kicad 5.1 (#13)
    * Update: ai03's Type-C library
    * Update: schematic to Kicad 5.1
    * Update: Type-C HRO footprint to fix DRC error
    * Update: Rename Gerbers to match new convention
    * Update: PCB minor version
    This version has the same pad layout, and the version 7 stencil will
    still work for it.
    [Matrix.sch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]
2020-06-09 Update elecrow production files (#14)
    * Update: Generate BOM for new components
    * Update: Work on Elecrow fabrication files
    * Update: Add parts mapping image
    [CO60-PCBA-Quotation.xlsx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]
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2020-06-10 Fix: Inconsistencies in BOM
    [CO60-PCBA-Quotation.xlsx]
